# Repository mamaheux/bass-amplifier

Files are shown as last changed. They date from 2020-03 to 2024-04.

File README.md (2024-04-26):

# Bass-Amplifier
Bass-Amplifier is a project to create our own bass guitar amplifier. The amplifier features are:
 - Digital sound processing
 - Footswitch
 - Tuner output
 - XLR and jack direct output
 - Effect send and return
 - Contour and presence filters
 - 4-band EQ
 - Compressor effect
 - Overdrive effect
 - Octaver effect
 - Delay effect
 - Reverb effect

## Folder Descriptions
### cases
This folder contains the CAD files to create the cases.
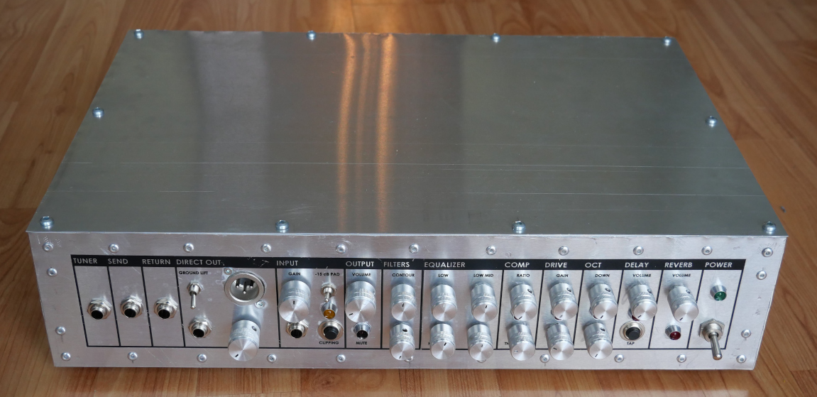
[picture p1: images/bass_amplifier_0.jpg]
Image of bass amplifier

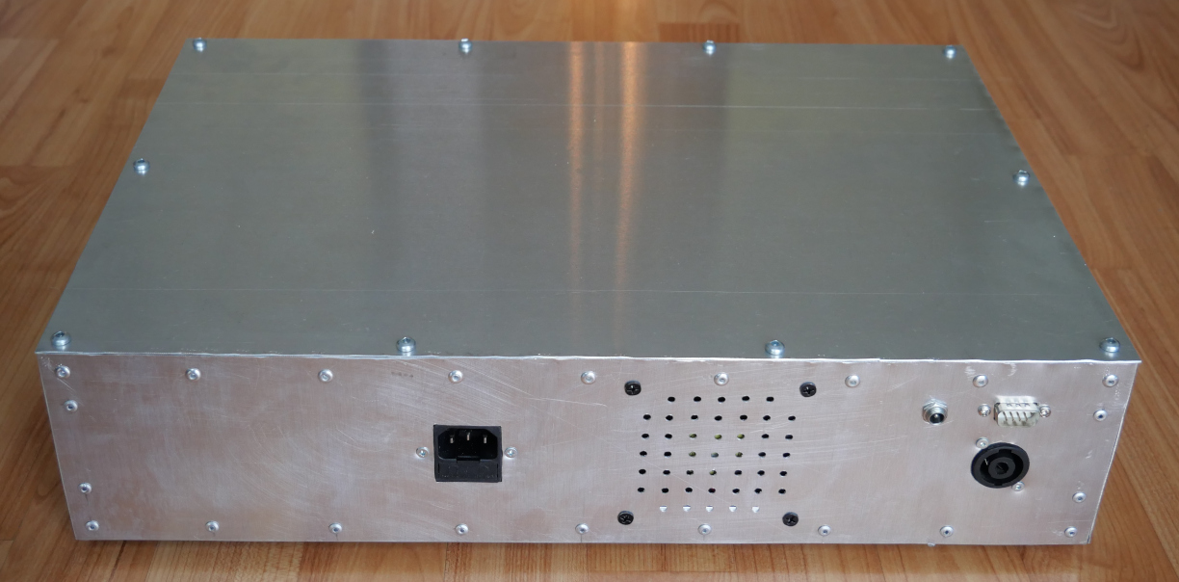
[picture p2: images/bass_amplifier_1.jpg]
Image of bass amplifier

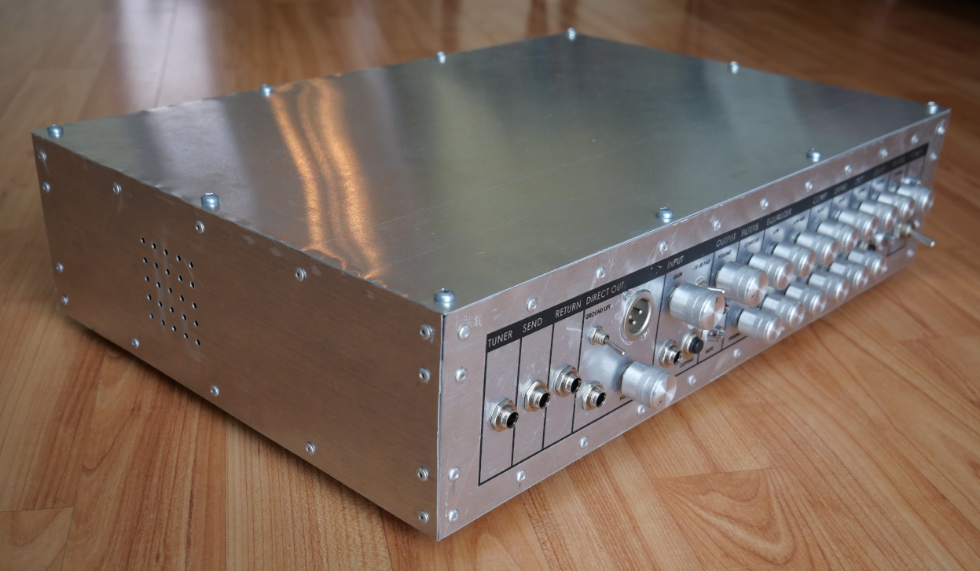
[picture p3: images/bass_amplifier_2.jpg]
Image of bass amplifier

Image of bass amplifier
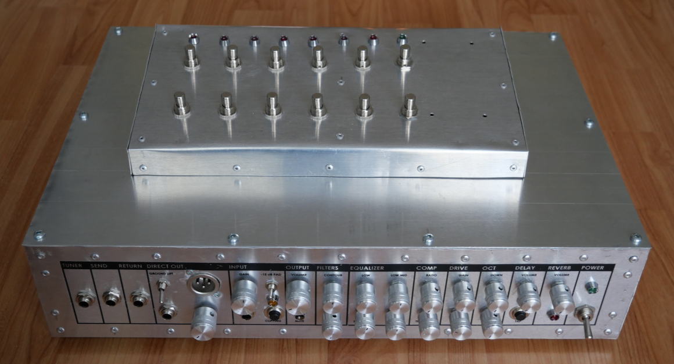
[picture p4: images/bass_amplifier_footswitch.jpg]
Image of bass amplifier


### code
This folder contains the MCU source code for the footswitch, the bass amplifier signal processor and the bass amplifier controller.

### electronics
This folder contains the schematics and PCB layouts of the bass amplifier.

### tools/signal_processing
This folder contains a Python tool to test the audio effects.
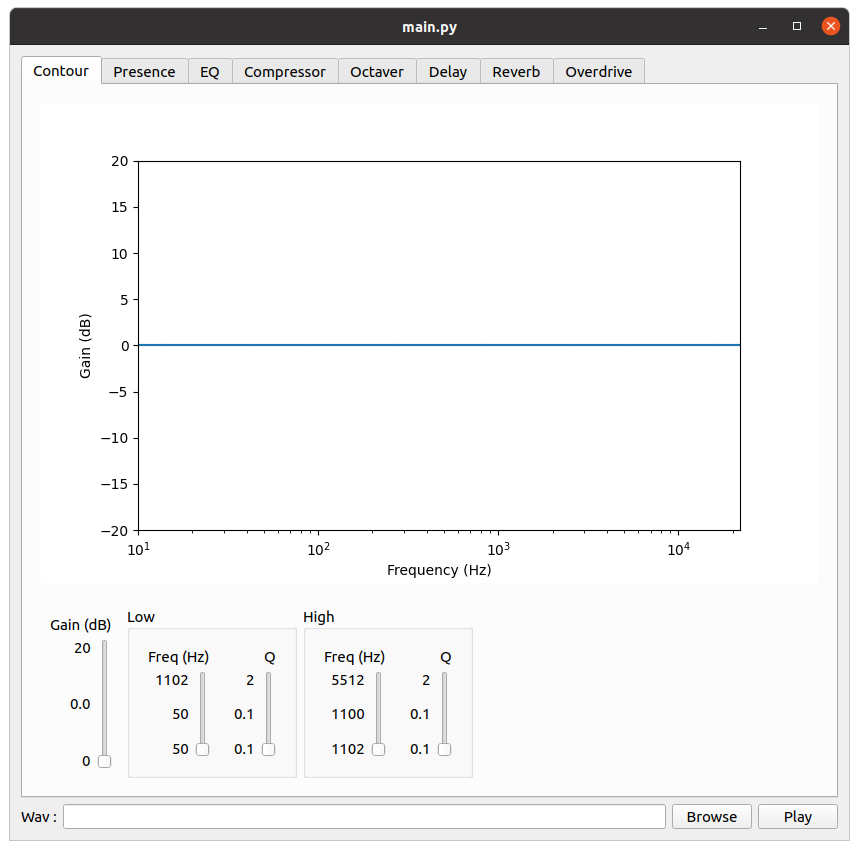
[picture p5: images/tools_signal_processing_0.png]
Image of bass amplifier

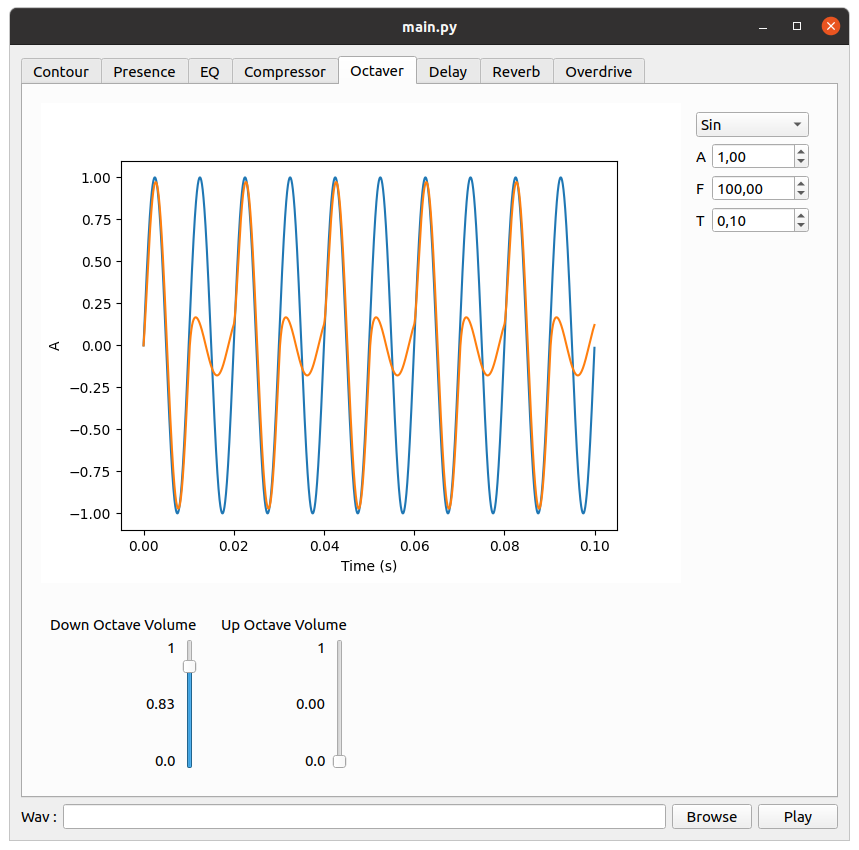
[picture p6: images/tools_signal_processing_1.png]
Image of bass amplifier


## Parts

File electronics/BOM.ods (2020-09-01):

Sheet: control
Item | Qty | Reference(s) | Value | LibPart | Sample | Link
1 | 2 | C1, C2 | 1000µF/25V | Device:CP |  | https://www.futurlec.com/Capacitors/C1000U25Epr.shtml
2 | 2 | C3, C4 | 2.2µF/25V/UL ESR | Device:C |  | https://www.digikey.ca/product-detail/en/taiyo-yuden/TMK212B7225MGHT/587-6358-1-ND/9949944
3 | 2 | C5, C9 | 1µF/10V/UL ESR | Device:C |  | https://www.digikey.ca/product-detail/en/taiyo-yuden/LMK212B7105KGHTR/587-6338-1-ND/9949924
4 | 14 | C6, C7, C10, C11, C12, C13, C14, C16, C17, C18, C19, C20, C21, C22 | 1µF/16V | Device:C |  | https://www.digikey.ca/product-detail/en/kemet/C0805C105Z4VACTU/399-8011-1-ND/3471734
5 | 7 | C8, C15, C23, C24, C25, C26, C27 | 0.1µF/25V | Device:C |  | https://www.digikey.ca/product-detail/en/kemet/C0805C104M3RACTU/399-8000-1-ND/3471723
6 | 2 | D1, D2 | LED_PAD | bass_amplifier:LED_4X
7 | 2 | J1, J3 | Conn_01x06_Male | Connector:Conn_01x06_Male
8 | 1 | J2 | Conn_01x02_Male | Connector:Conn_01x02_Male
9 | 4 | Q1, Q2, Q3, Q4 | TD9944 | bass_amplifier:TD9944 | Yes | https://www.digikey.ca/product-detail/en/microchip-technology/TD9944TG-G/TD9944TG-GCT-ND/7671946
10 | 5 | R1, R2, R3, R4, R5 | 10k | Device:R
11 | 7 | RV1, RV2, RV3, RV4, RV5, RV6, RV7 | 10k | Device:R_POT_Dual_Separate |  | https://futurlec.com/Potentiometers/POT10Kpr.shtml | https://futurlec.com/Switches/KNOB18.shtml
12 | 1 | SW1 | SW_SPST_X3 | bass_amplifier:SW_SPST_X3 |  | https://futurlec.com/Switches/PRBLKpr.shtml
13 | 1 | TH1 | 10k | Device:Thermistor_NTC |  | https://www.futurlec.com/Components_Others/NTC10Kpr.shtml
14 | 1 | U1 | Teensy_LC | bass_amplifier:Teensy_LC |  | https://www.pjrc.com/store/teensylc.html
15 | 1 | U2 | MCP3208 | bass_amplifier:MCP3208 | Yes | https://www.digikey.ca/product-detail/en/microchip-technology/MCP3208-CI-SL/MCP3208-CI-SL-ND/305929
16 | 1 | U3 | 74HC14 | bass_amplifier:74HC14 |  | https://www.digikey.ca/product-detail/en/nexperia-usa-inc/74HC14D-652/1727-3781-ND/763534
17 | 1 | U4 | MAX3232 | bass_amplifier:MAX3232 |  | https://www.digikey.ca/product-detail/en/texas-instruments/MAX3232ECDR/296-19851-1-ND/1120592
18 | 1 | Transformer | Transformer |  |  | https://www.digikey.ca/en/products/detail/triad-magnetics/VPT36-1390/2090072

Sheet: footswitch
Item | Qty | Reference(s) | Value | LibPart | Sample | Link
1 | 17 | C1, C2, C5, C8, C9, C10, C11, C12, C13, C16, C17, C18, C19, C20, C21, C22, C23 | 0.1µF/25V | Device:C |  | https://www.digikey.ca/product-detail/en/kemet/C0805C104M3RACTU/399-8000-1-ND/3471723
2 | 2 | C3, C4 | 1000µF/25V | Device:CP |  | https://www.futurlec.com/Capacitors/C1000U25Epr.shtml
3 | 2 | C6, C7 | 2.2µF/25V/UL low ESR | Device:C |  | https://www.digikey.ca/product-detail/en/taiyo-yuden/TMK212B7225MGHT/587-6358-1-ND/9949944
4 | 2 | C14, C15 | 1µF/10V/UL ESR | Device:C |  | https://www.digikey.ca/product-detail/en/taiyo-yuden/LMK212B7105KGHTR/587-6338-1-ND/9949924
5 | 2 | D1, D2 | LED | bass_amplifier:LED_4X
6 | 1 | J1 | control | Connector:Conn_01x06_Male
7 | 4 | Q1, Q2, Q3, Q4 | TD9944 | bass_amplifier:TD9944 | Yes | https://www.digikey.ca/product-detail/en/microchip-technology/TD9944TG-G/TD9944TG-GCT-ND/7671946
8 | 24 | R1, R2, R3, R4, R5, R6, R7, R8, R9, R10, R11, R12, R13, R14, R15, R16, R17, R18, R19, R20, R21, R22, R23, R24 | 10k | Device:R
9 | 3 | SW1, SW2, SW3 | SPST | bass_amplifier:SW_SPST_X4
10 | 1 | U1 | Teensy_LC | bass_amplifier:Teensy_LC |  | https://www.pjrc.com/store/teensylc.html
11 | 2 | U2, U3 | 74HC14 | bass_amplifier:74HC14 |  | https://www.digikey.ca/product-detail/en/nexperia-usa-inc/74HC14D-652/1727-3781-ND/763534
12 | 1 | U4 | MAX3232 | bass_amplifier:MAX3232 |  | https://www.digikey.ca/product-detail/en/texas-instruments/MAX3232ECDR/296-19851-1-ND/1120592

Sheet: psu
Item | Qty | Reference(s) | Value | LibPart | Sample | Link
1 | 2 | C1, C2 | 10000µF/35V | Device:CP |  | https://www.digikey.ca/product-detail/en/tdk-electronics-inc/B41231A7109M000/495-6149-ND/3493505
2 | 7 | C3, C4, C5, C6, C10, C16, C25, C28 | 1µF/35V | Device:C |  | https://www.digikey.ca/product-detail/en/taiyo-yuden/GMK212B7105KG-T/587-1438-1-ND/1004069
3 | 6 | C7, C8, C14, C20, C22, C23 | 2.2µF/25V/UL ESR | Device:C |  | https://www.digikey.ca/product-detail/en/taiyo-yuden/TMK212B7225MGHT/587-6358-1-ND/9949944
4 | 2 | C9, C15 | 33µF/35V/260mOhm | Device:CP |  | https://www.digikey.ca/product-detail/en/panasonic-electronic-components/EEE-FP1V330AP/PCE4551CT-ND/1701050
5 | 2 | C11, C17 | 0.33µF | Device:C |  | https://www.digikey.ca/product-detail/en/w%C3%BCrth-elektronik/885012207101/732-7676-1-ND/5454303
6 | 2 | C12, C18 | 0.1µF | Device:C |  | https://www.digikey.ca/product-detail/en/kemet/C0805C104M3RACTU/399-8000-1-ND/3471723
7 | 1 | C13 | 330µF/16V/160mOhm | Device:CP |  | https://www.digikey.ca/en/products/detail/united-chemi-con/EMZR160ADA331MF80G/5824761
8 | 1 | C19 | 330µF/6.3V/160mOhm | Device:CP |  | https://www.digikey.ca/product-detail/en/panasonic-electronic-components/EEE-FPJ331XAP/PCE4517CT-ND/1701016
9 | 2 | C21, C24, C27 | 470µF/16V | Device:CP |  | https://www.futurlec.com/Capacitors/C470U16Epr.shtml
10 | 1 | C26 | 47µF/6.3V | Device:C |  | https://www.digikey.ca/product-detail/en/murata-electronics/GRM219R60J476ME44D/490-13249-1-ND/5877457
11 | 1 | D1 | BR81 | Diode_Bridge:ABS2 |  | https://www.futurlec.com/Diodes/BR81pr.shtml
12 | 2 | D2, D3 | SS34/40V/4A | Device:D_Schottky |  | https://www.digikey.ca/product-detail/en/on-semiconductor/SS34/SS34FSCT-ND/2094459
13 | 1 | D4 | LED | Device:LED
14 | 2 | F1, F2 | 1.5A | Device:Fuse |  | https://www.futurlec.com/Components_Others/520FUSES1A5pr.shtml
15 | 1 | F3 | 0.5A | Device:Fuse |  | https://www.futurlec.com/Components_Others/520FUSES0A5pr.shtml
16 | 1 | J1 | Conn_01x03_Female | Connector:Conn_01x03_Female
17 | 1 | J2 | control board | Connector:Conn_01x06_Male
18 | 1 | J3 | processing | Connector:Conn_01x08_Male
19 | 1 | J4 | processing | Connector:Conn_01x06_Male
20 | 1 | J5 | pedals | Connector:Conn_01x02_Male
21 | 1 | J6 | FAN | Connector:Conn_01x02_Male
22 | 2 | L1, L2 | 68µH/Sumida CDRH104R-680MC | Device:L |  | https://www.digikey.ca/product-detail/en/sumida-america-components-inc/CDRH104RNP-680NC/308-2170-1-ND/3946461
23 | 1 | Q1 | PHB21N06LT | Device:Q_NMOS_DGS |  | https://www.digikey.ca/en/products/detail/nexperia-usa-inc/PHB21N06LT-118/1157487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
24 | 5 | R1, R2, R5, R8, R9 | 0 | Device:R
25 | 2 | R3, R6 | 3.01k | Device:R
26 | 1 | R4 | 348 | Device:R
27 | 1 | R7 | 976 | Device:R
28 | 1 | R10 | 16.5k | Device:R
29 | 1 | R11 | 10k | Device:R
30 | 2 | R13, R14 | inf | Device:R
31 | 1 | R15 | 309 | Device:R
32 | 1 | U1 | MC7815 | bass_amplifier:MC7815 |  | https://www.digikey.ca/en/products/detail/on-semiconductor/MC7815CD2TR4G/919342
33 | 1 | U2 | MC7915 | bass_amplifier:MC7915 |  | https://www.digikey.ca/product-detail/en/on-semiconductor/MC7915CD2TR4G/MC7915CD2TR4GOSCT-ND/3462351
34 | 2 | U3, U4 | MIC4684 | bass_amplifier:MIC4684 | Yes | https://www.digikey.ca/product-detail/en/microchip-technology/MIC4684YM-TR/576-1553-1-ND/1121890
35 | 1 | U5 | MC7809 | bass_amplifier:MC7809 |  | https://www.digikey.ca/product-detail/en/on-semiconductor/MC7809CD2TR4G/MC7809CD2TR4GOSCT-ND/3487393
36 | 1 | U6 | MIC37152 | bass_amplifier:MIC37152 | Yes | https://www.digikey.ca/product-detail/en/microchip-technology/MIC37152YM-TR/MIC37152YM-CT-ND/9923709
37 | 1 | U7 | NIS5112 | bass_amplifier:NIS5112 |  | https://www.digikey.ca/product-detail/en/on-semiconductor/NIS5112D2R2G/NIS5112D2R2GOSCT-ND/3487452

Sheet: processing
Item | Qty | Reference(s) | Value | LibPart | Sample | Link
1 | 4 | C1, C2, C3, C4 | 1000µF/25V | Device:CP |  | https://www.futurlec.com/Capacitors/C1000U25Epr.shtml
2 | 22 | C5, C6, C7, C8, C9, C10, C11, C12, C13, C14, C15, C16, C17, C18, C30, C34, C35, C37, C55, C56, C57, C58 | 2.2µF/25V/UL ESR | Device:C |  | https://www.digikey.ca/product-detail/en/taiyo-yuden/TMK212B7225MGHT/587-6358-1-ND/9949944
3 | 1 | C19 | 100pF/100V | Device:C |  | https://www.digikey.ca/product-detail/en/samsung-electro-mechanics/CL21C101JCANNNC/1276-1261-1-ND/3889347
4 | 2 | C20, C24 | 220pF/100V | Device:C |  | https://www.digikey.ca/product-detail/en/samsung-electro-mechanics/CL21B221KCANNNC/1276-2476-1-ND/3890562
5 | 9 | C21, C26, C28, C29, C33, C36, C41, C42, C46 | 10µF/50V | Device:C |  | https://www.digikey.ca/product-detail/en/samsung-electro-mechanics/CL31A106MBHNNNE/1276-6736-1-ND/5961595
6 | 1 | C22 | 0.1µF/100V | Device:C |  | https://www.digikey.ca/product-detail/en/samsung-electro-mechanics/CL21B104KCFSFNE/1276-2923-1-ND/3891009
7 | 1 | C23 | 0.22µF/100V | Device:C |  | https://www.digikey.ca/product-detail/en/samsung-electro-mechanics/CL21B224KCFSFNE/1276-2949-1-ND/3891035
8 | 1 | C25 | 1nF/100V | Device:C |  | https://www.digikey.ca/product-detail/en/samsung-electro-mechanics/CL21B102KCANNNC/1276-1169-1-ND/3889255
9 | 3 | C27, C31, C32 | 4.7nF/100V | Device:C |  | https://www.digikey.ca/product-detail/en/samsung-electro-mechanics/CL21B472KCANNNC/1276-2524-1-ND/3890610
10 | 1 | C38 | 0.047µF/100V | Device:C |  | https://www.digikey.ca/product-detail/en/w%C3%BCrth-elektronik/885012207126/732-12090-1-ND/9346110
11 | 2 | C39, C40 | 3.3µF/25V | Device:C |  | https://www.digikey.ca/product-detail/en/w%C3%BCrth-elektronik/885012107017/732-7627-1-ND/5454254
12 | 1 | C43 | 3600pF/50V | Device:C |  | https://www.digikey.ca/product-detail/en/murata-electronics/GRM2165C1H362JA01D/490-3318-1-ND/702859
13 | 2 | C44, C45 | 220pF/50V | Device:C |  | https://www.digikey.ca/product-detail/en/kemet/C0805C221M5RACTU/399-8039-1-ND/3471762
14 | 4 | C47, C48, C53, C54 | 0.1µF/25V | Device:C |  | https://www.digikey.ca/product-detail/en/yageo/CC0603KRX7R8BB104/311-1341-1-ND/2103125
15 | 1 | C49 | 47µF/10V | Device:C |  | https://www.digikey.ca/product-detail/en/taiyo-yuden/LMK212BBJ476MG-T/587-5465-1-ND/7067141
16 | 1 | C50 | 10µF/10V | Device:C |  | https://www.digikey.ca/product-detail/en/murata-electronics/GRM21BR71A106KA73L/490-10516-1-ND/5026447
17 | 2 | C51, C52 | 1µF/6.3V | Device:C |  | https://www.digikey.ca/product-detail/en/yageo/CC0805KKX5R5BB105/311-3417-1-ND/7164438
18 | 8 | D1, D2, D3, D4, D5, D6, D7, D8 | 12V | Device:D_Zener_ALT |  | https://www.futurlec.com/Diodes/BZV55-C12pr.shtml
19 | 2 | D9, D10 | 6.2V | Device:D_Zener_ALT |  | https://www.futurlec.com/Diodes/BZV55-C6V2pr.shtml
20 | 1 | J1 | Conn_01x08_Male | Connector:Conn_01x08_Male
21 | 1 | J2 | Conn_01x06_Male | Connector:Conn_01x06_Male
22 | 1 | J3 | power_amp | Connector:Conn_01x02_Male
23 | 1 | J4 | control board | Connector:Conn_01x03_Male
24 | 1 | J5 | AudioJack2_X4 | bass_amplifier:AudioJack2_X4
25 | 1 | J6 | AudioJack2_XLR_SW | bass_amplifier:AudioJack2_XLR_SW
26 | 1 | J7 | Conn_01x03_Male | Connector:Conn_01x03_Male
27 | 2 | Q1, Q2 | TD9944 | bass_amplifier:TD9944 | Yes | https://www.digikey.ca/product-detail/en/microchip-technology/TD9944TG-G/TD9944TG-GCT-ND/7671946
28 | 1 | Q3 | MMUN2111LT1 | Device:Q_PNP_ECB_BRT |  | https://www.digikey.ca/product-detail/en/on-semiconductor/MMUN2111LT1G/MMUN2111LT1GOSCT-ND/1139907
29 | 1 | Q4 | MMBT2222A | Device:Q_NPN_BCE |  | https://www.digikey.ca/product-detail/en/diodes-incorporated/MMBT2222A-7-F/MMBT2222A-FDICT-ND/815723
30 | 8 | R1, R4, R5, R8, R16, R18, R21, R70 | 0 | Device:R
31 | 4 | R2, R6, R11, R19 | inf | Device:R
32 | 16 | R3, R12, R15, R30, R31, R38, R39, R42, R43, R48, R49, R53, R56, R57, R63, R65 | 10k | Device:R
33 | 1 | R7 | 47.5k | Device:R
34 | 1 | R9 | 12.1K | Device:R
35 | 1 | R10 | 1M | Device:R
36 | 1 | R13 | 12.1k | Device:R
37 | 1 | R14 | 221 | Device:R
38 | 1 | R17 | 2.21k | Device:R
39 | 1 | R20 | 56.2k | Device:R
40 | 1 | R22 | 23.7k | Device:R
41 | 8 | R23, R24, R27, R28, R35, R46, R47, R50 | 5.11k | Device:R
42 | 5 | R25, R29, R44, R45, R51 | 20k | Device:R
43 | 2 | R26, R34 | 10.2k | Device:R
44 | 4 | R32, R33, R40, R41 | 1k | Device:R
45 | 2 | R36, R37 | 100k | Device:R
46 | 1 | R52 | 4.75k | Device:R
47 | 7 | R54, R55, R59, R60, R66, R68, R69 | 2k | Device:R
48 | 2 | R58, R61 | 470 | Device:R
49 | 1 | R62 | 3.09k | Device:R
50 | 1 | R64 | 15.4k | Device:R
51 | 1 | R67 | 560 | Device:R
52 | 2 | R71, R72 | inf or 47k | Device:R
53 | 1 | RV1 | 10k | Device:R_POT_Dual_Separate
54 | 1 | RV_SW1 | 10k | bass_amplifier:R_POT_SW
55 | 4 | U1, U2, U4, U5 | TL074 | bass_amplifier:TL074 |  | https://www.digikey.ca/product-detail/en/texas-instruments/TL074CDR/296-1283-1-ND/404931
56 | 2 | U3, U10 | TL072 | bass_amplifier:TL072 |  | https://www.digikey.ca/product-detail/en/stmicroelectronics/TL072CDT/497-2200-1-ND/599107
57 | 1 | U6 | Teensy_4.0 | bass_amplifier:Teensy_4.0
58 | 1 | U7 | MCP6541 | bass_amplifier:MCP6541 |  | https://www.digikey.ca/product-detail/en/microchip-technology/MCP6541T-I-SN/MCP6541T-I-SNCT-ND/8538051
59 | 1 | U8 | SN74LVC2G74 | bass_amplifier:SN74AUC1G74 |  | https://www.digikey.ca/en/products/detail/texas-instruments/SN74LVC2G74DCTR/484721
60 | 1 | U9 | CS4270 | bass_amplifier:CS4270 |  | https://www.digikey.ca/product-detail/en/cirrus-logic-inc/CS4270-CZZ/598-1040-5-ND/923160

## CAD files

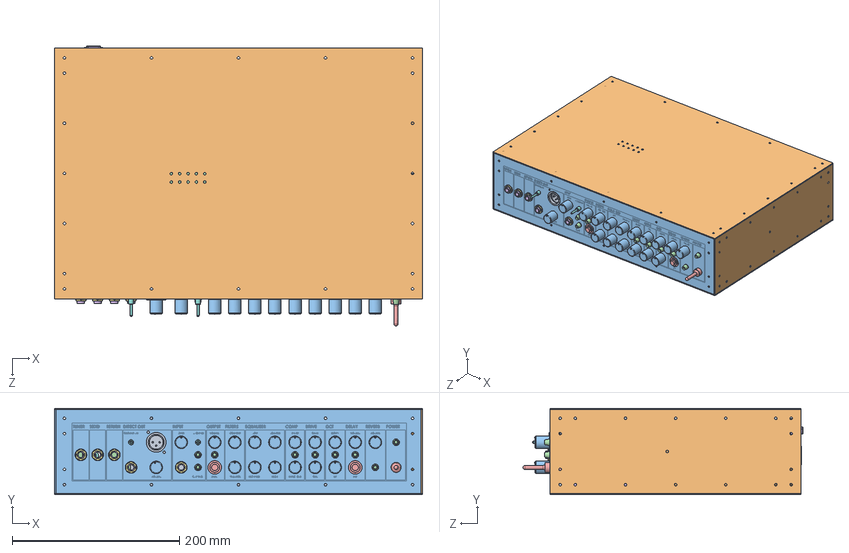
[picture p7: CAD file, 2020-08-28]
cases/amplifier/case.SLDASM
440.0 x 103.2 x 334.7 mm
bottom
transformer_600VA_50V
transformer_50VA_18V
pcb_psu
diode_bridge
power_cap
pcb_amp
pcb_processing
pcb_controller
side_right
side_left
side_back
iec_c14
fan_80mm.step
standoff_m3_10mm x 12
speakon
middle
top
side_front
led_green
toggle_sw_hd
jack x 5
jack_nut x 5
toggle_sw x 2
xlr
pot x 17
knob x 17
led_red x 8
button x 2
dsub-9

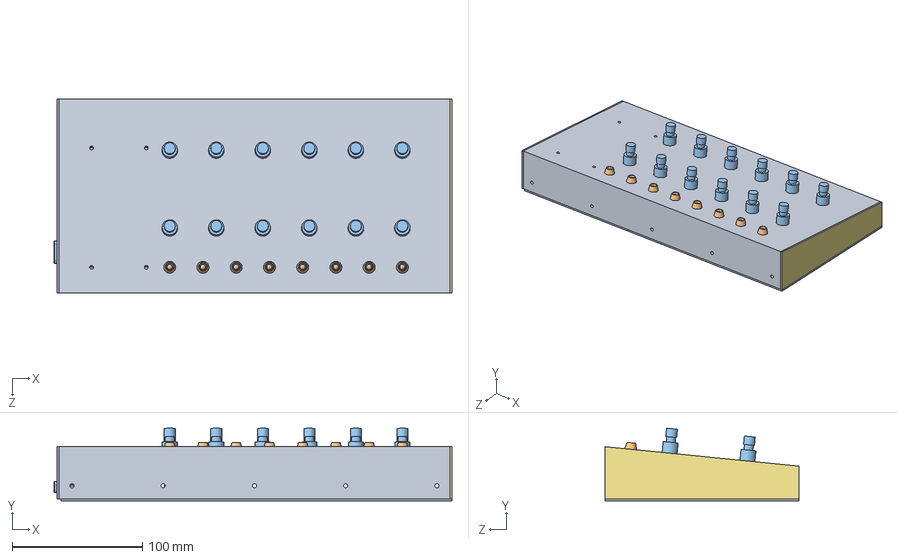
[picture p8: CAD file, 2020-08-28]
cases/footswitch/case.SLDASM
305.4 x 55.8 x 149.2 mm
top
led_red x 8
sw x 12
standoff_m3_10mm x 4
pcb
side_right
side_left
dsub-9
bottom

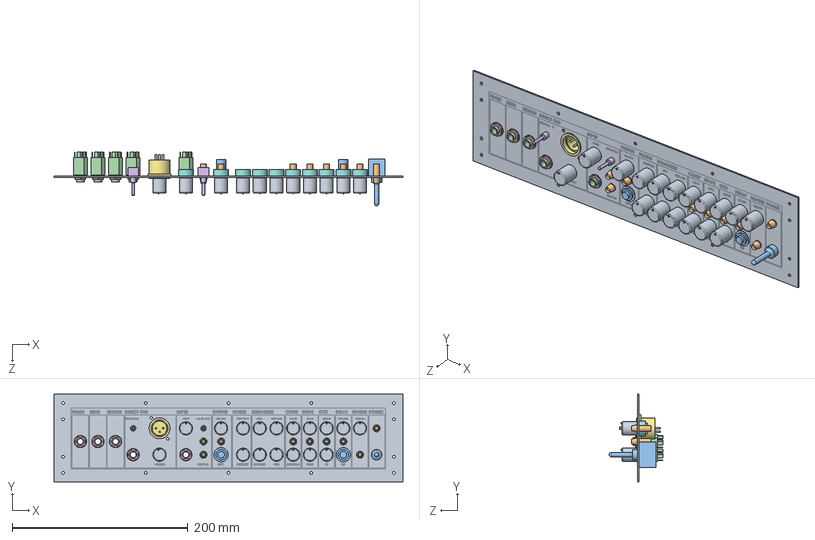
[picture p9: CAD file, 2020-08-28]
cases/amplifier/front.SLDASM
396.8 x 100.0 x 61.0 mm
side_front
led_green
toggle_sw_hd
jack x 5
jack_nut x 5
toggle_sw x 2
xlr
pot x 17
knob x 17
led_red x 8
button x 2

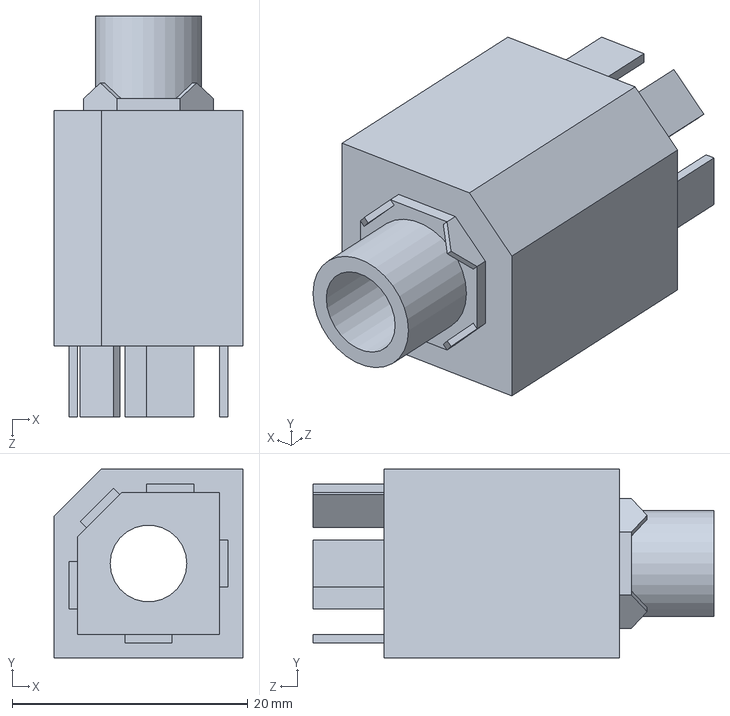
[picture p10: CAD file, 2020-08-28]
cases/amplifier/pieces/jack.SLDPRT
16.0 x 16.0 x 34.0 mm

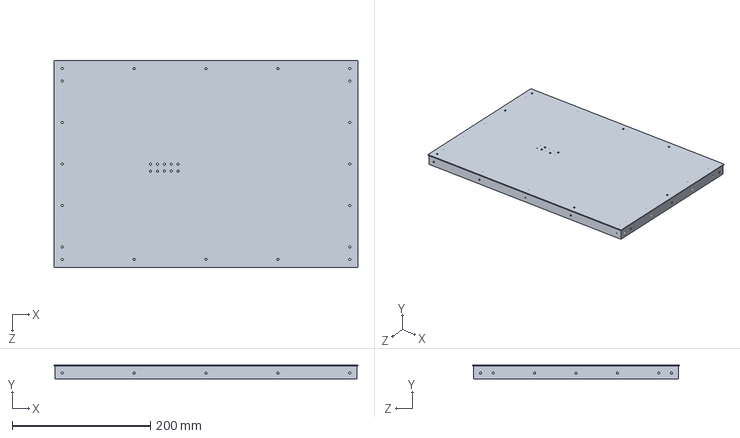
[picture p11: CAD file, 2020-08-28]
cases/amplifier/plates/top.SLDPRT
440.0 x 20.6 x 300.0 mm

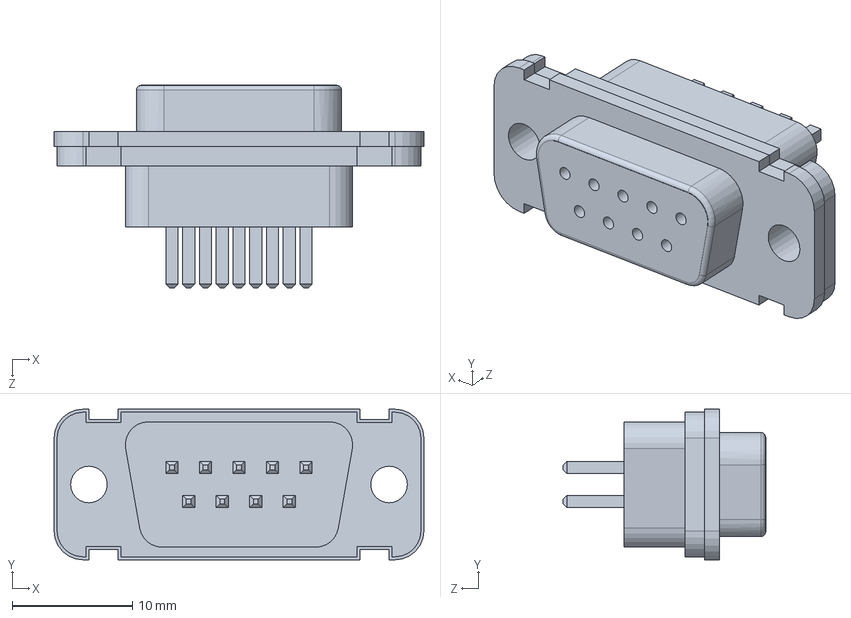
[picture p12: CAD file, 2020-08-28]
cases/footswitch/pieces/dsub-9.SLDPRT
30.8 x 12.5 x 16.9 mm

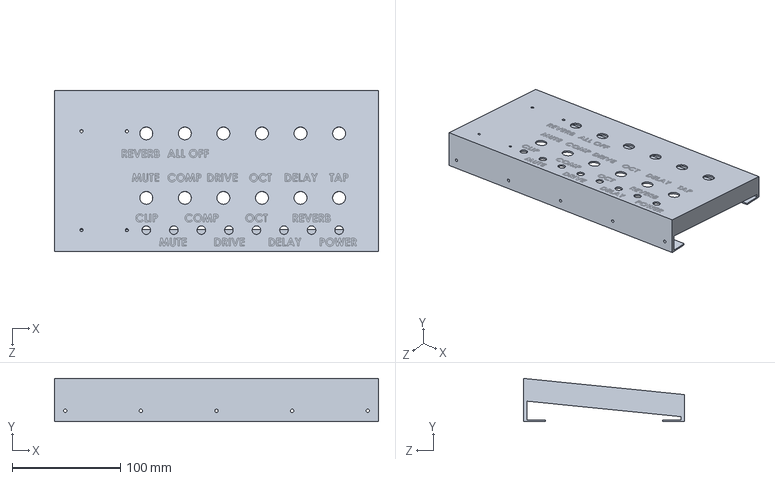
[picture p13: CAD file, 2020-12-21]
cases/footswitch/plates/top.SLDPRT
300.0 x 40.0 x 149.2 mm

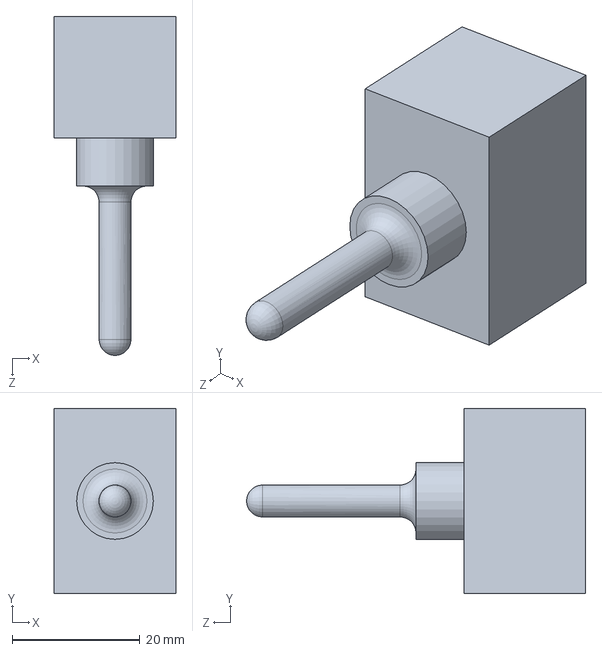
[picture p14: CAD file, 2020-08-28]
cases/amplifier/pieces/toggle_sw_hd.SLDPRT
19.0 x 29.0 x 53.0 mm

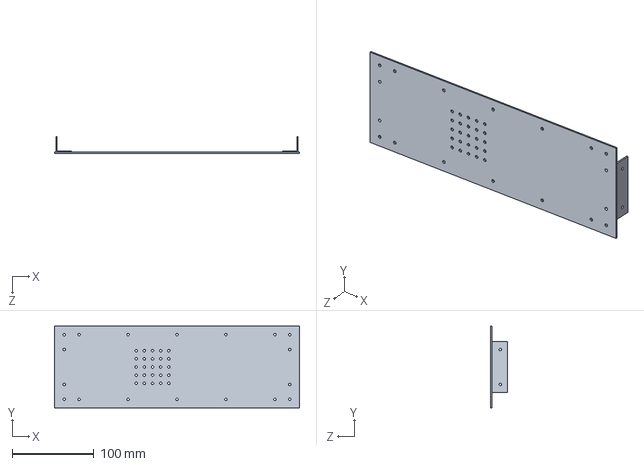
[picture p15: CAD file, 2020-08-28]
cases/amplifier/plates/side_left.SLDPRT
300.0 x 100.0 x 20.6 mm

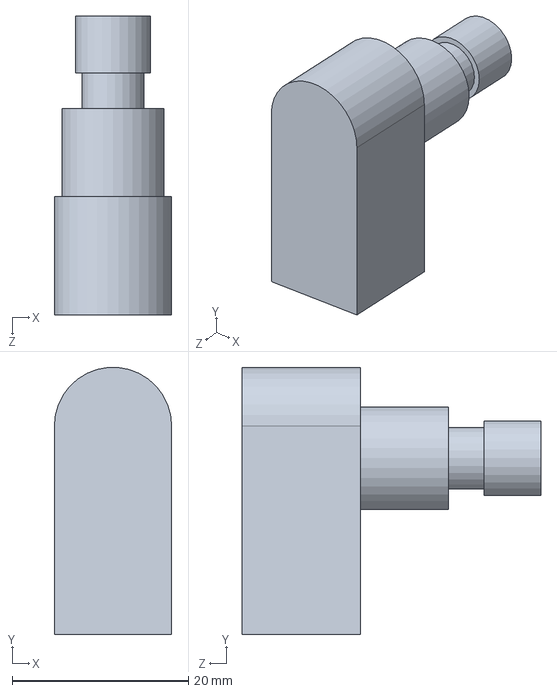
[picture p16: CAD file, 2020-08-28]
cases/footswitch/pieces/sw.SLDPRT
13.3 x 30.3 x 33.8 mm

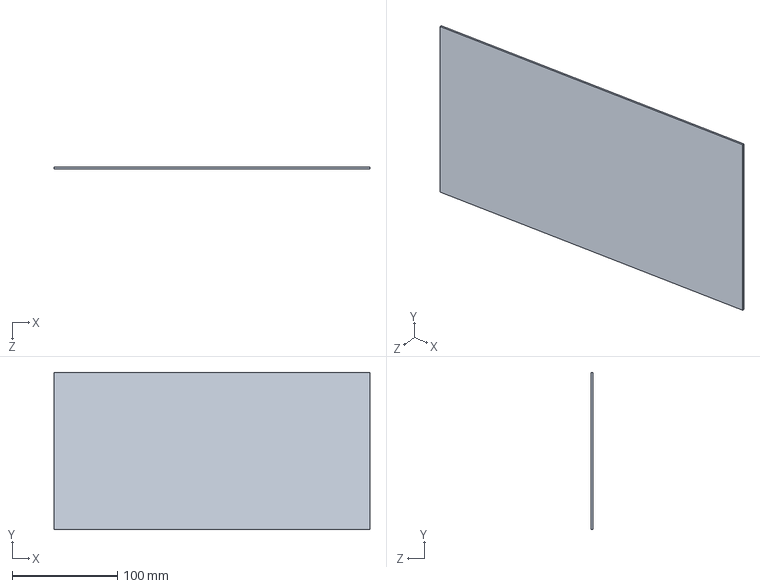
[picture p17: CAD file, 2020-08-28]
cases/footswitch/plates/bottom.SLDPRT
300.0 x 149.2 x 1.59 mm

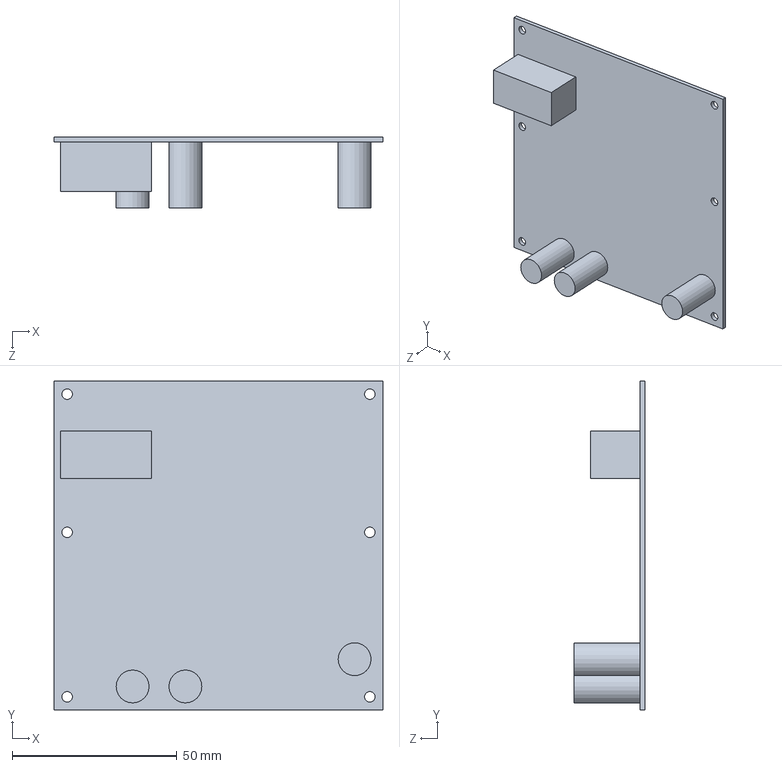
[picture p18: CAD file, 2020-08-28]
cases/amplifier/pieces/pcb_processing.SLDPRT
100.0 x 100.0 x 21.6 mm

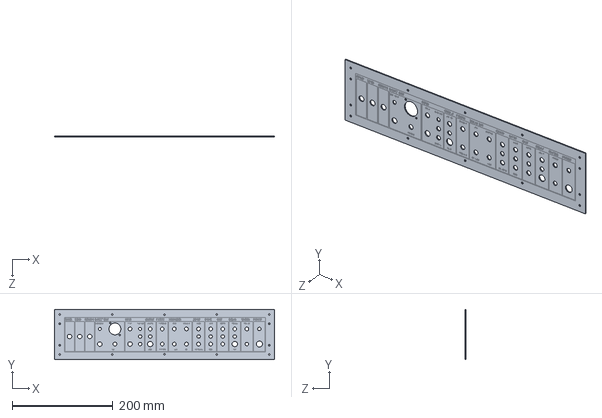
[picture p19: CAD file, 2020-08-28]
cases/amplifier/plates/side_front.SLDPRT
436.8 x 100.0 x 1.59 mm

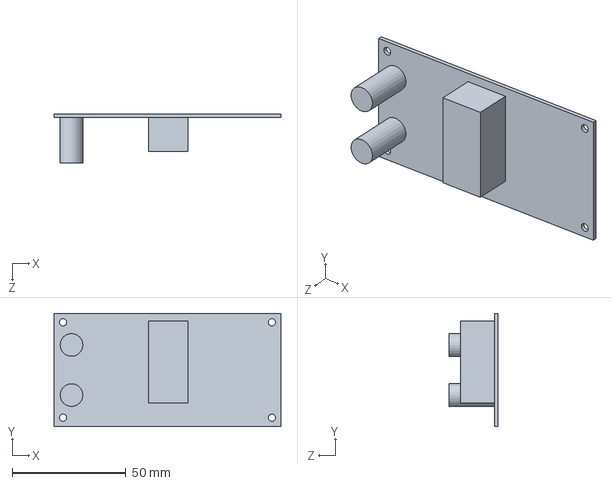
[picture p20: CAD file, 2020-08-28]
cases/footswitch/pieces/pcb.SLDPRT
100.0 x 50.0 x 21.6 mm

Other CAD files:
cases/footswitch/plates/side_right.SLDPRT
cases/amplifier/pieces/led_green.SLDPRT
cases/amplifier/plates/middle.SLDPRT
cases/footswitch/pieces/led_red.SLDPRT
cases/amplifier/pieces/button.SLDPRT
cases/amplifier/pieces/diode_bridge.SLDPRT
cases/amplifier/pieces/fan_80mm.step.SLDPRT
cases/amplifier/pieces/iec_c14.SLDPRT
cases/amplifier/pieces/jack_nut.SLDPRT
cases/amplifier/pieces/knob.SLDPRT
cases/amplifier/pieces/led_red.SLDPRT
cases/amplifier/pieces/pcb_amp.SLDPRT
cases/amplifier/pieces/pcb_psu.SLDPRT
cases/amplifier/pieces/pot.SLDPRT
cases/amplifier/pieces/power_cap.SLDPRT
cases/amplifier/pieces/speakon.SLDPRT
cases/amplifier/pieces/standoff_m3_10mm.SLDPRT
cases/amplifier/pieces/toggle_sw.SLDPRT
cases/amplifier/pieces/transformer_50VA_18V.SLDPRT
cases/amplifier/pieces/transformer_600VA_50V.SLDPRT
cases/amplifier/pieces/xlr.SLDPRT
cases/amplifier/plates/bottom.SLDPRT
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

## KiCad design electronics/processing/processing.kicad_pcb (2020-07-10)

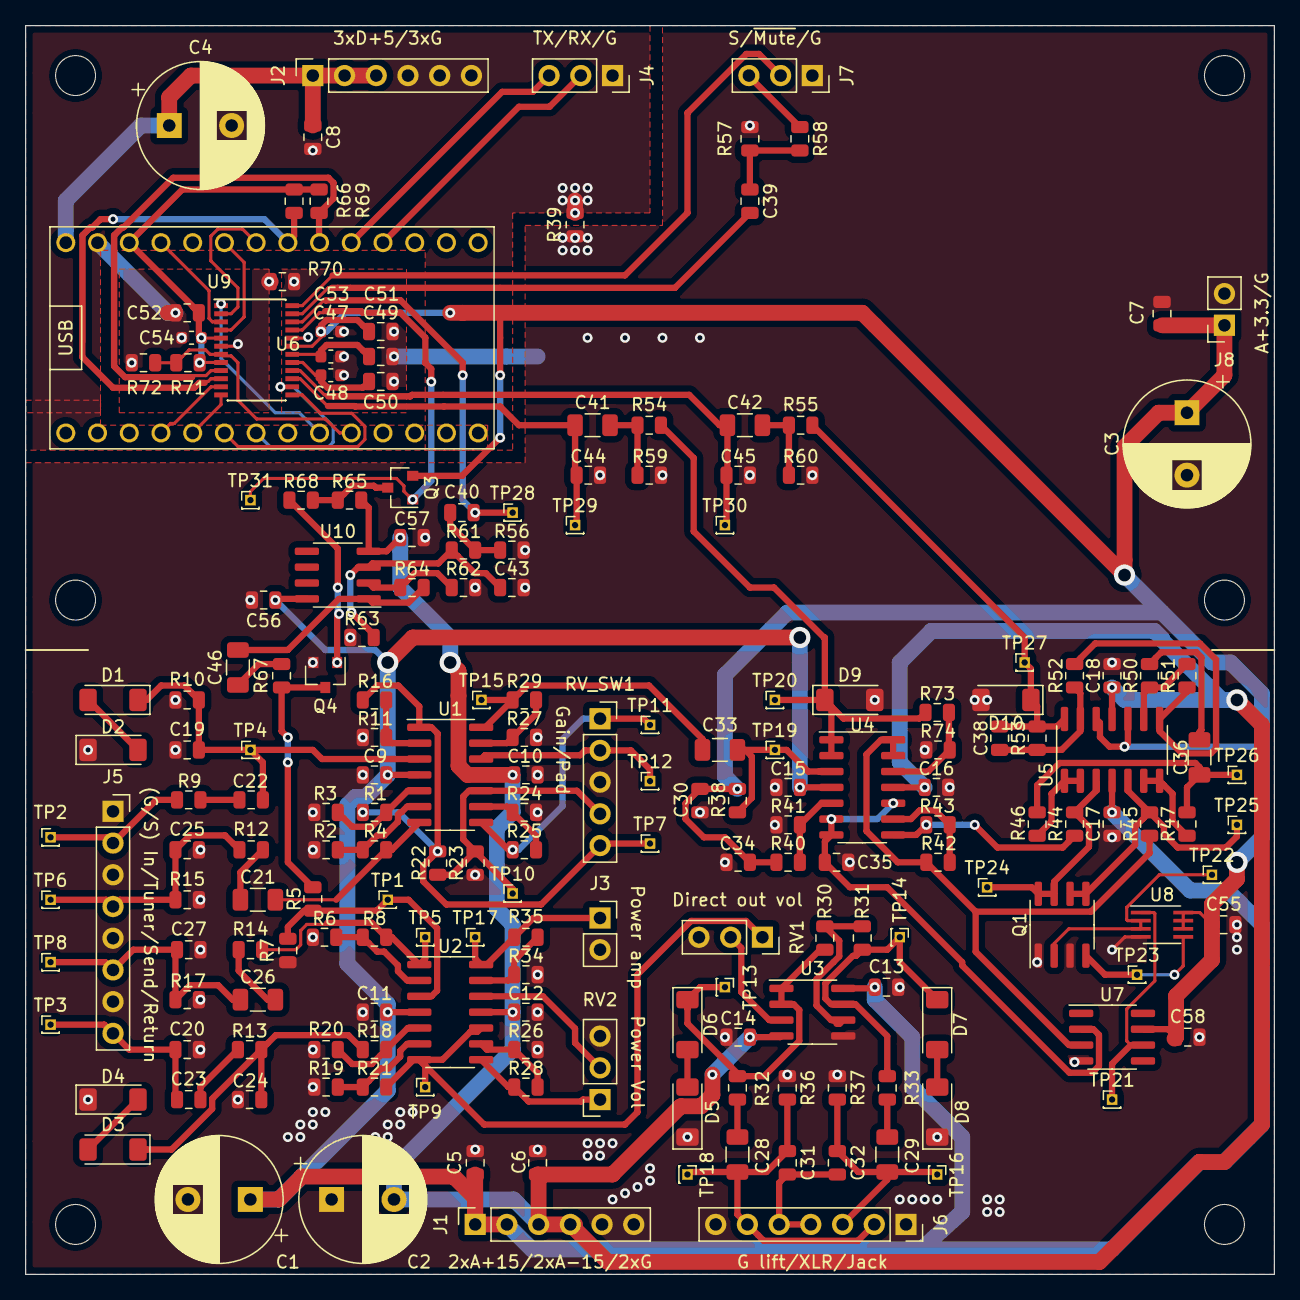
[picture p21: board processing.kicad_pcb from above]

Board: 2 copper layers, 100.0 x 100.0 mm, 194 parts (0 on the bottom side), 106 nets.

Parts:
C1, C2, C3, C4: 1000µF/25V; CP_Radial_D10.0mm_P5.00mm
C5, C6, C7, C8, C9, C10, C11, C12, C13, C14, C15, C16, C17, C18, C30, C34, C35, C55, C56, C57, C58: 2.2µF/25V/UL ESR; C_0805_2012Metric
C19: 100pF/100V; C_0805_2012Metric
C20, C24: 220pF/100V; C_0805_2012Metric
C21, C26, C28, C29, C33, C36, C41, C42, C46: 10µF/50V; C_1206_3216Metric
C22: 0.1µF/100V; C_0805_2012Metric
C23: 0.22µF/100V; C_0805_2012Metric
C25: 1nF/100V; C_0805_2012Metric
C27, C31, C32: 4.7nF/100V; C_0805_2012Metric
C38: 0.047µF/100V; C_0805_2012Metric
C39, C40: 3.3µF/25V; C_0805_2012Metric
C43: 3600pF/50V; C_0805_2012Metric
C44, C45: 220pF/50V; C_0805_2012Metric
C47, C48, C53, C54: 0.1µF/25V; C_0603_1608Metric
C49: 47µF/10V; C_0805_2012Metric
C50: 10µF/10V; C_0805_2012Metric
C51, C52: 1µF/6.3V; C_0805_2012Metric
D1, D2, D3, D4, D5, D6, D7, D8: 12V; D_1806_4516Metric
D9, D10: 6.2V; D_1806_4516Metric
J1, J2: Conn_01x06_Male; PinSocket_1x06_P2.54mm_Vertical
J3: power_amp; PinSocket_1x02_P2.54mm_Vertical
J4: control board; PinSocket_1x03_P2.54mm_Vertical
J5: AudioJack2_X4; PinSocket_1x08_P2.54mm_Vertical
J6: AudioJack2_XLR_SW; PinSocket_1x07_P2.54mm_Vertical
J7: Conn_01x03_Male; PinSocket_1x03_P2.54mm_Vertical
J8: Conn_01x02_Male; PinSocket_1x02_P2.54mm_Vertical
Q1: TD9944; SOIC-8_3.9x4.9mm_P1.27mm
Q3: MMUN2111LT1; SOT-23
Q4: MMBT2222A; SOT-23
R1, R4, R5, R8, R16, R18, R21, R39, R70: 0; R_0805_2012Metric
R2, R6, R11, R19: inf; R_0805_2012Metric
R3, R12, R15, R30, R31, R38, R40, R41, R42, R43, R53, R56, R57, R63, R65, R73, R74: 10k; R_0805_2012Metric
R7: 47.5k; R_0805_2012Metric
R9: 12.1K; R_0805_2012Metric
R10: 1M; R_0805_2012Metric
R13: 12.1k; R_0805_2012Metric
R14: 221; R_0805_2012Metric
R17: 2.21k; R_0805_2012Metric
R20: 56.2k; R_0805_2012Metric
R22: 23.7k; R_0805_2012Metric
R23, R24, R27, R28, R35, R46, R47, R50: 5.11k; R_0805_2012Metric
R25, R29, R44, R45, R51: 20k; R_0805_2012Metric
R26, R34: 10.2k; R_0805_2012Metric
R32, R33: 1k; R_0805_2012Metric
R36, R37: 100k; R_0805_2012Metric
R52: 4.75k; R_0805_2012Metric
R54, R55, R59, R60, R66, R68, R69: 2k; R_0805_2012Metric
R58, R61: 470; R_0805_2012Metric
R62: 3.09k; R_0805_2012Metric
R64: 15.4k; R_0805_2012Metric
R67: 560; R_0805_2012Metric
R71, R72: inf or 47k; R_0805_2012Metric
RV1, RV2: R_POT; PinSocket_1x03_P2.54mm_Vertical
RV_SW1: 10k; PinSocket_1x05_P2.54mm_Vertical
TP1, TP2, TP3, TP4, TP5, TP6, TP7, TP8, TP9, TP10, TP11, TP12, TP13, TP14, TP15, TP16, TP17, TP18, TP19, TP20, TP21, TP22, TP23, TP24, TP25, TP26, TP27, TP28, TP29, TP30, TP31: TP; PinHeader_1x01_P1.00mm_Vertical
U1, U2, U4, U5: TL074; SOIC-14_3.9x8.7mm_P1.27mm
U3, U10: TL072; SOIC-8_3.9x4.9mm_P1.27mm
U6: Teensy_4.0
U7: MCP6541; SOIC-8_3.9x4.9mm_P1.27mm
U8: SN74AUC1G74; SSOP-8_2.95x2.8mm_P0.65mm
U9: CS4270; TSSOP-24_4.4x7.8mm_P0.65mm

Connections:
/LRCLK: U6.20, U9.2
/MCLK: U6.23, U9.3
/MCU_3.3V: C52.1, C54.1, R66.1, R69.1, R71.2, U6.3V3_1, U9.5, U9.8
/SCL: R66.2, U6.19, U9.10
/SCLK: U6.21, U9.4
/SDA: R69.2, U6.18, U9.9
/SDIN: U6.7, U9.1
/SDOUT: R71.1, R72.2, U6.8, U9.7
/analog/octaver_down/REF+1.65V: C35.1, U4.6, U4.7, U4.10, U7.2
/analog/octaver_down/half_signal_in: R42.2, R45.2, U4.13, U4.14, U7.3
/analog/power_amp_signal: J3.1, R35.1, TP17.1, U2.14
/codec/AD0: U6.2, U9.11
/codec/AD1: U6.3, U9.12
/codec/AD2: U6.4, U9.13
/codec/ADC_input_A: D9.1, R54.2, R73.2, TP20.1, U4.1, U4.2
/codec/ADC_input_B: C38.1, D10.1, R53.1, R55.2, TP27.1, U5.14
/codec/DAC_output: Q4.3, R5.2, R67.1
/codec/INA: C41.1, C44.2, TP29.1, U9.15
/codec/INB: C42.1, C45.2, TP30.1, U9.16
/codec/OUTA: C40.2, TP28.1, U9.22
/codec/OUTB: C39.2, U9.23
/codec/~MUTEA: Q3.1, TP31.1, U9.21
/codec/~MUTEB: J7.2, U9.24
/codec/~RST: U6.5, U9.14
A+3.3V: C3.1, C7.1, C30.1, C34.1, C51.1, C53.1, C55.1, C58.1, J8.1, Q3.2, R38.1, R40.2, U5.10, U5.12, U7.7, U8.6, U8.7, U8.8, U9.19
A+15V: C1.1, C5.1, C9.1, C11.1, C13.1, C15.1, C17.1, C56.1, J1.1, J1.2, U1.4, U2.4, U3.8, U4.4, U5.4, U10.8
A-15V: C2.2, C6.2, C10.1, C12.1, C14.1, C16.1, C18.1, C57.1, J1.3, J1.4, R65.1, U1.11, U2.11, U3.4, U4.11, U5.11, U10.4
D+5V: C4.1, C8.1, J2.1, J2.2, J2.3, U6.VIN
GNDA: C1.2, C2.1, C3.2, C5.2, C6.1, C7.2, C9.2, C10.2, C11.2, C12.2, C13.2, C14.2, C15.2, C16.2, C17.2, C18.2, C19.1, C20.2, C24.2, C25.2, C27.2, C30.2, C34.2, C35.2, C43.1, C44.1, C45.1, C47.2, C48.1, C49.2, C50.1, C51.2, C53.2, C55.2, C56.2, C57.2, C58.2, D2.1, D4.1, D5.1, D8.1, D9.2, D10.2, J1.5, J1.6, J3.2, J5.1, J5.3, J5.5, J5.7, J6.1, J6.7, J7.1, J8.2, Q1.1, Q1.3, Q4.2, R2.2, R3.1, R6.2, R7.1, R10.1, R11.2, R15.2, R17.1, R19.2, R20.1, R23.1, R24.2, R26.2, R27.2, R34.2, R36.1, R37.1, R39.1, R41.1, R56.1, R57.1, R59.1, R60.1, R62.2, R63.1, R70.1, R74.1, RV1.3, RV2.3, RV_SW1.3, U3.5, U7.4, U8.4, U9.20
GNDD: C4.2, C8.2, C52.2, C54.2, J2.4, J2.5, J2.6, J4.1, R39.2, R70.2, R72.1, U6.GND_2, U9.6
unnamed: C19.2, C22.1, D1.1, R10.2, TP4.1, U1.3
unnamed: C20.1, C23.1, J5.8, TP3.1
unnamed: C21.1, R12.2
unnamed: C21.2, R4.1, U1.7
unnamed: C22.2, R9.1
unnamed: C23.2, R13.2
unnamed: C24.1, D3.1, R13.1, R18.2
unnamed: C25.1, J5.4, R12.1, R15.1, TP6.1
unnamed: C26.1, C27.1, J5.6, R17.2, TP8.1
unnamed: C26.2, R14.1
unnamed: C28.1, C31.1, J6.2, J6.6, R36.2, TP18.1
unnamed: C28.2, R32.1
unnamed: C29.1, C32.1, J6.3, R37.2, TP16.1
unnamed: C29.2, R33.1
unnamed: C31.2, C32.2, J6.4, J6.5
unnamed: C33.1, R38.2, TP19.1, U4.3
unnamed: C33.2, R29.1, TP15.1, U1.14
unnamed: C36.1, R50.2
unnamed: C36.2, R46.1, R47.2, TP26.1
unnamed: C38.2, R52.1, R53.2, U5.13
unnamed: C39.1, R57.2, R58.2
unnamed: C40.1, R56.2, R61.2
unnamed: C41.2, R54.1, R59.2
unnamed: C42.2, R55.1, R60.2
unnamed: C43.2, R61.1, R63.2, U10.3
unnamed: C46.1, R67.2
unnamed: C46.2, R64.1, U10.1
unnamed: C47.1, C49.1, U9.18
unnamed: C48.2, C50.2, U9.17
unnamed: D1.2, D2.2
unnamed: D3.2, D4.2
unnamed: D5.2, D6.2
unnamed: D6.1, R30.1, R32.2, TP13.1, U3.1, U3.2
unnamed: D7.1, R31.1, R33.2, TP14.1, U3.7
unnamed: D7.2, D8.2
unnamed: J4.2, U6.16
unnamed: J4.3, U6.17
unnamed: J5.2, R9.2, TP2.1
unnamed: J7.3, R58.1
unnamed: Q1.2, TP22.1, U8.2, U8.3
unnamed: Q1.4, TP23.1, U8.5
unnamed: Q1.5, Q1.6, R45.1, TP25.1, U5.5
unnamed: Q1.7, Q1.8, R44.1, TP24.1, U5.3
unnamed: Q3.3, R65.2, R68.1
unnamed: Q4.1, R68.2
unnamed: R1.1, R3.2, U1.5
unnamed: R1.2, R16.1, R22.2, RV_SW1.5, TP7.1, U1.1
unnamed: R2.1, R4.2, U1.6
unnamed: R5.1, R7.2, TP1.1, U2.3
unnamed: R6.1, R8.2, U2.2
unnamed: R11.1, R16.2, U1.2
unnamed: R8.1, R14.2, TP5.1, U2.1
unnamed: R18.1, R20.2, U2.5
unnamed: R19.1, R21.2, U2.6
unnamed: R21.1, RV1.1, TP9.1, U2.7, U2.10
unnamed: R22.1, R23.2, RV_SW1.4, TP10.1, U1.10
unnamed: R24.1, R25.2, U1.9
unnamed: R25.1, RV_SW1.1, TP11.1, U1.8
unnamed: R26.1, R28.2, U2.9
unnamed: R27.1, R29.2, U1.13
unnamed: R28.1, RV2.1, U2.8
unnamed: R30.2, R31.2, U3.6
unnamed: R34.1, R35.2, U2.13
unnamed: R40.1, R41.2, U4.5
unnamed: R42.1, R43.2, U4.9
unnamed: R43.1, R44.2, U4.8
unnamed: R46.2, U5.1, U5.2
unnamed: R47.1, U5.6, U5.7
unnamed: R50.1, R51.2, U5.9
unnamed: R51.1, R52.2, U5.8
unnamed: R62.1, R64.2, U10.2
unnamed: R73.1, R74.2, U4.12
unnamed: RV1.2, U3.3
unnamed: RV2.2, U2.12
unnamed: RV_SW1.2, TP12.1, U1.12
unnamed: TP21.1, U7.6, U8.1

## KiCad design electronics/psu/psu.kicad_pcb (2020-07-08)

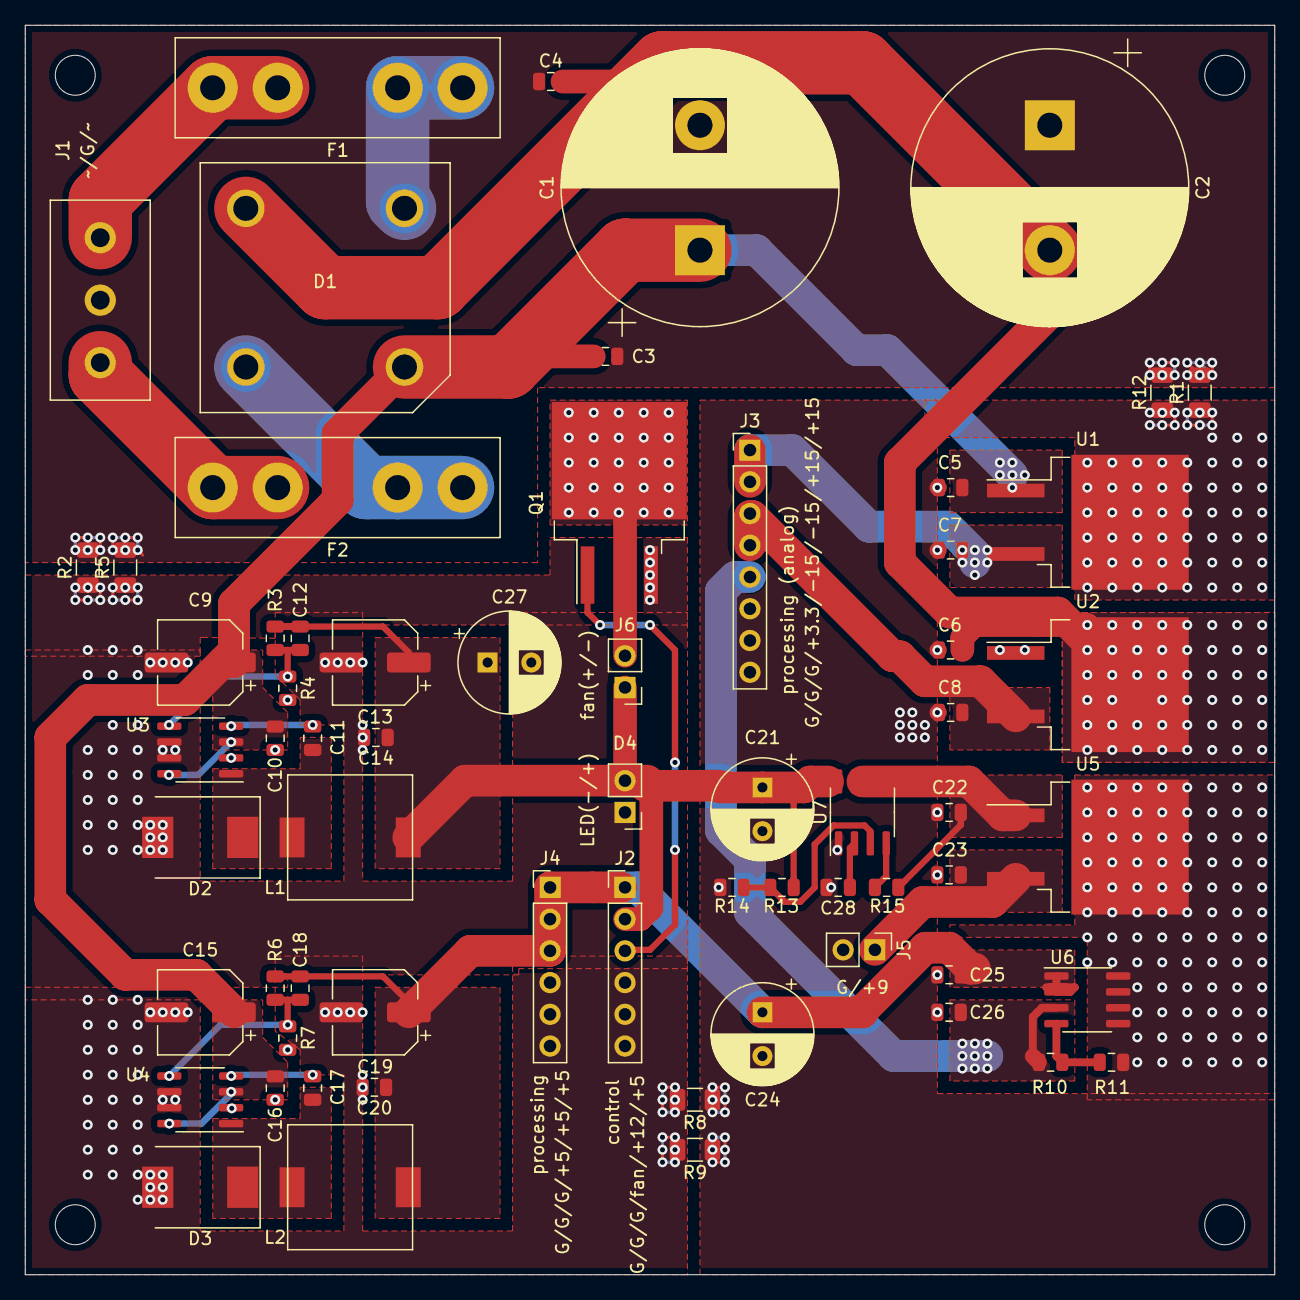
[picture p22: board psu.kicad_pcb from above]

Board: 2 copper layers, 100.0 x 100.0 mm, 65 parts (0 on the bottom side), 28 nets.

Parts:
C1, C2: 10000µF/35V; CP_Radial_D22.0mm_P10.00mm_SnapIn
C3, C4, C5, C6, C10, C16, C25: 1µF/35V; C_0805_2012Metric
C7, C8, C14, C20, C22, C23: 2.2µF/25V/UL ESR; C_0805_2012Metric
C9, C15: 33µF/35V/260mOhm; CP_Elec_6.3x7.7
C11, C17: 0.33µF; C_0805_2012Metric
C12, C18: 0.1µF; C_0805_2012Metric
C13, C19: 330µF/6.3V/160mOhm; CP_Elec_6.3x7.7
C21, C24, C27: 470µF/16V; CP_Radial_D8.0mm_P3.50mm
C26: 47µF/6.3V; C_0805_2012Metric
C28: C; C_0805_2012Metric
D1: BR81
D2, D3: SS34/40V/4A; D_SMC
D4: LED; PinHeader_1x02_P2.54mm_Vertical
F1, F2: 1.5A; M205_FUSE
J1: Conn_01x03_Female; transformer_connector
J2: control board; PinHeader_1x06_P2.54mm_Vertical
J3: processing; PinHeader_1x08_P2.54mm_Vertical
J4: processing; PinHeader_1x06_P2.54mm_Vertical
J5: pedals; PinHeader_1x02_P2.54mm_Vertical
J6: FAN; PinHeader_1x02_P2.54mm_Vertical
L1, L2: 68µH/Sumida CDRH104R-680MC; CDRH104RNP-680NC
Q1: PHB21N06LT; TO-263-2
R1, R2, R5, R8, R9, R12: 0; R_1206_3216Metric
R3, R6: 3.01k; R_0805_2012Metric
R4: 348; R_0805_2012Metric
R7: 976; R_0805_2012Metric
R10: 16.5k; R_0805_2012Metric
R11: 10k; R_0805_2012Metric
R13, R14: inf; R_0805_2012Metric
R15: 309; R_0805_2012Metric
U1: MC7815; TO-263-2
U2: MC7915; TO-263-2
U3, U4: MIC4684; SOIC-8_3.9x4.9mm_P1.27mm
U5: MC7809; TO-263-2
U6: MIC37152; SOIC-8_3.9x4.9mm_P1.27mm
U7: NIS5112; SOIC-8_3.9x4.9mm_P1.27mm

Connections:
/+20V: C1.1, C3.1, C5.1, C9.1, C10.1, C15.1, C16.1, D1.1, U1.1, U3.3, U3.8, U4.3, U4.8
/-20V: C2.2, C4.2, C6.2, D1.2, U2.2
/A+3.3V: C26.1, J3.5, R10.1, U6.3
/A+9V: C23.1, J5.1, U5.3
/A+15V: C7.1, J3.1, J3.2, U1.3
/A-15V: C8.2, J3.3, J3.4, U2.3
/D+5V: C18.1, C19.1, C20.1, C24.1, C25.1, J2.1, J4.1, J4.2, J4.3, L2.2, R6.1, U6.1, U6.2
/D+12V: C12.1, C13.1, C14.1, C21.1, C27.1, D4.2, J2.2, J6.1, L1.2, R3.1, R13.2, U7.8
/fan/fan_pwm: J2.3, Q1.1
GND: C1.2, C2.1, C3.2, C4.1, J1.2, R1.2, R2.2, R5.2, R12.2
GNDA: C5.2, C6.1, C7.2, C8.1, C21.2, C22.2, C23.2, C24.2, C25.2, C26.2, C28.2, J3.6, J3.7, J3.8, J5.2, R1.1, R8.1, R9.1, R11.2, R12.1, R14.2, U1.2, U2.1, U5.2, U6.5, U6.6, U6.7, U6.8, U7.1
GNDD: C9.2, C10.2, C13.2, C14.2, C15.2, C16.2, C19.2, C20.2, C27.2, D2.2, D3.2, D4.1, J2.4, J2.5, J2.6, J4.4, J4.5, J4.6, Q1.3, R2.1, R4.2, R5.1, R7.2, R8.2, R9.2, U3.2, U3.6, U3.7, U4.2, U4.6, U4.7
unnamed: C11.1, U3.4
unnamed: C11.2, D2.1, L1.1, U3.1
unnamed: C12.2, R3.2, R4.1, U3.5
unnamed: C17.1, U4.4
unnamed: C17.2, D3.1, L2.1, U4.1
unnamed: C18.2, R6.2, R7.1, U4.5
unnamed: C22.1, R15.2, U5.1, U7.5, U7.6, U7.7
unnamed: C28.1, U7.2
unnamed: D1.3, F2.1
unnamed: D1.4, F1.1
unnamed: F1.2, J1.3
unnamed: F2.2, J1.1
unnamed: J6.2, Q1.2
unnamed: R10.2, R11.1, U6.4
unnamed: R13.1, R14.1, U7.3
unnamed: R15.1, U7.4

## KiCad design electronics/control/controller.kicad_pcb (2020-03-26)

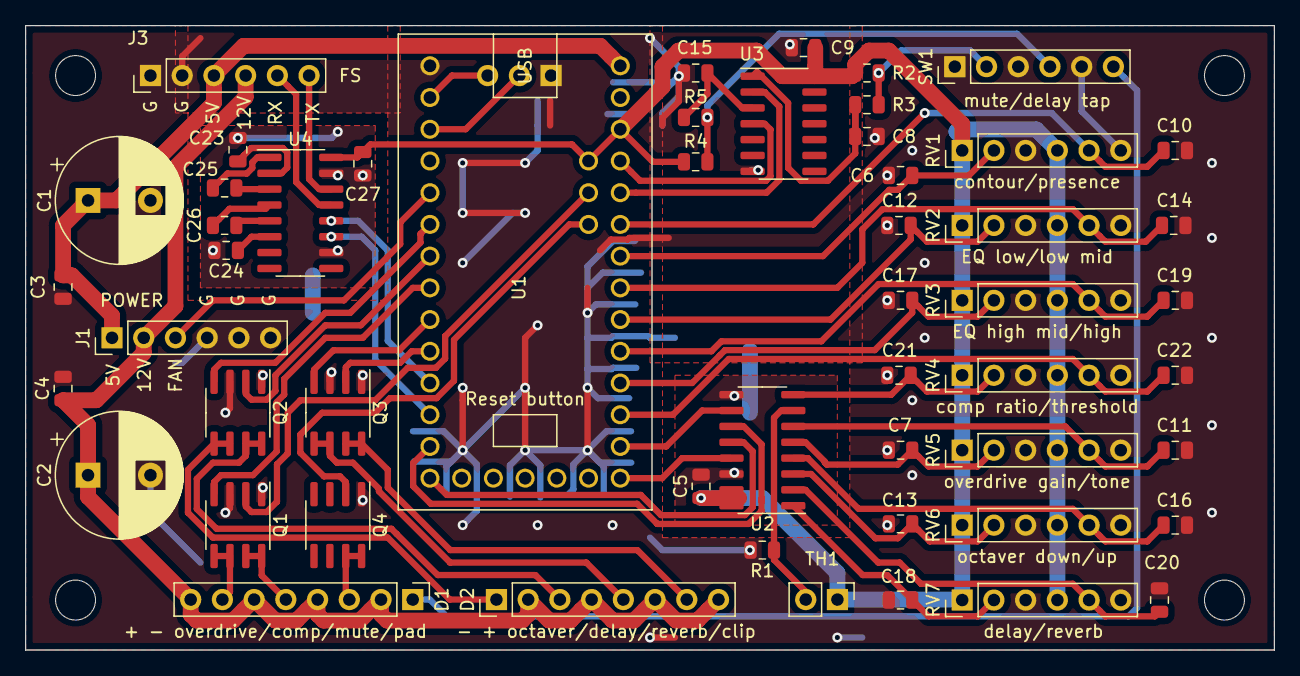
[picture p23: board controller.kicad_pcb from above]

Board: 2 copper layers, 100.0 x 50.0 mm, 54 parts (1 on the bottom side), 57 nets.

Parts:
C1, C2: 1000µF/25V; CP_Radial_D10.0mm_P5.00mm
C3, C4: 2.2µF/25V/UL low ESR; C_0805_2012Metric
C5, C9: 1µF/10V/UL ESR; C_0805_2012Metric
C6, C7, C10, C11, C12, C13, C14, C16, C17, C18, C19, C20, C21, C22: 1µF/16V; C_0805_2012Metric
C8, C15: 0.1µF/25V; C_0805_2012Metric
C23, C24, C25, C26, C27: 0.1µF; C_0805_2012Metric
D1, D2: LED; PinHeader_1x08_P2.54mm_Vertical
J1: Conn_01x06_Male; PinHeader_1x06_P2.54mm_Vertical
J2: Conn_01x03_Male; PinHeader_1x03_P2.54mm_Vertical
J3: footswitch; PinHeader_1x06_P2.54mm_Vertical
Q1, Q2, Q3, Q4: TD9944; SOIC-8_3.9x4.9mm_P1.27mm
R1, R2, R3, R4, R5: 10k; R_0805_2012Metric
RV1, RV2, RV3, RV4, RV5, RV6, RV7: 10k; PinHeader_1x06_P2.54mm_Vertical
SW1: SW_SPST_X3; PinHeader_1x06_P2.54mm_Vertical
TH1: 10k; PinHeader_1x02_P2.54mm_Vertical
U1: Teensy_LC
U2: MCP3208; SOIC-16_3.9x9.9mm_P1.27mm
U3: 74HC14; SOIC-14_3.9x8.7mm_P1.27mm
U4: MAX3232; SOIC-16_3.9x9.9mm_P1.27mm

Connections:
/MCU/3V3: C5.1, C9.1, C27.1, R2.1, R4.1, RV1.1, RV1.4, RV2.1, RV2.4, RV3.1, RV3.4, RV4.1, RV4.4, RV5.1, RV5.4, RV6.1, RV6.4, RV7.1, RV7.4, TH1.1, U1.3V3_1, U1.AREF, U2.15, U2.16, U3.14, U4.16
/MCU/ADC_CS: U1.14, U2.10
/MCU/ADC_MISO: U1.12, U2.12
/MCU/ADC_MOSI: U1.11, U2.11
/MCU/ADC_SCK: U1.13, U2.13
/MCU/DSP_RX: J2.2, U1.1
/MCU/DSP_TX: J2.3, U1.0
/MCU/FS_RS232_RX: J3.5, U4.13
/MCU/FS_RS232_TX: J3.6, U4.14
/MCU/FS_RX: U1.9, U4.12
/MCU/FS_TX: U1.10, U4.11
/MCU/MCU_LED/clipping_LED: Q3.2, U1.8
/MCU/MCU_LED/delay_LED: Q2.2, U1.5
/MCU/MCU_LED/octaver_LED: Q2.4, U1.4
/MCU/MCU_LED/overdrive_LED: Q1.4, U1.6
/MCU/MCU_LED/reverb_LED: Q3.4, U1.7
/MCU/MCU_control_elements/EQ_high_mid_pot: C17.1, RV3.2, U1.16
/MCU/MCU_control_elements/EQ_high_pot: C19.1, RV3.5, U1.17
/MCU/MCU_control_elements/EQ_low_mid_pot: C14.1, RV2.5, U1.19
/MCU/MCU_control_elements/EQ_low_pot: C12.1, RV2.2, U1.18
/MCU/MCU_control_elements/comp_ratio_pot: C21.1, RV4.2, U2.8
/MCU/MCU_control_elements/comp_threshold_pot: C22.1, RV4.5, U1.15
/MCU/MCU_control_elements/contour_pot: C6.1, RV1.2, U1.20
/MCU/MCU_control_elements/delay_tap_button: U1.23, U3.4
/MCU/MCU_control_elements/delay_vol_pot: C18.1, RV7.2, U2.1
/MCU/MCU_control_elements/mute_sw: U1.22, U3.2
/MCU/MCU_control_elements/octaver_down_pot: C13.1, RV6.2, U2.3
/MCU/MCU_control_elements/octaver_up_pot: C16.1, RV6.5, U2.4
/MCU/MCU_control_elements/overdrive_gain_pot: C7.1, RV5.2, U2.5
/MCU/MCU_control_elements/overdrive_tone_pot: C11.1, RV5.5, U2.6
/MCU/MCU_control_elements/presence_pot: C10.1, RV1.5, U1.21
/MCU/MCU_control_elements/reverb_vol_pot: C20.1, RV7.5, U2.2
/MCU/V_temp: R1.1, TH1.2, U2.7
/MCU/comp_LED: Q1.2, U1.24
/MCU/fan_pwm: J1.3, U1.3
/MCU/mute_LED: Q4.2, U1.25
D+5V: C1.1, C3.1, J1.1, J3.3, U1.VIN
D+12V: C2.1, C4.1, D1.2, D1.4, D1.6, D1.8, D2.2, D2.4, D2.6, D2.8, J1.2, J3.4
GNDD: C1.2, C2.2, C3.2, C4.2, C5.2, C6.2, C7.2, C8.2, C9.2, C10.2, C11.2, C12.2, C13.2, C14.2, C15.2, C16.2, C17.2, C18.2, C19.2, C20.2, C21.2, C22.2, C23.2, C24.2, C27.2, J1.4, J1.5, J1.6, J2.1, J3.1, J3.2, Q1.1, Q1.3, Q2.1, Q2.3, Q3.1, Q3.3, Q4.1, R1.2, RV1.3, RV1.6, RV2.3, RV2.6, RV3.3, RV3.6, RV4.3, RV4.6, RV5.3, RV5.6, RV6.3, RV6.6, RV7.3, RV7.6, SW1.1, SW1.3, SW1.5, U1.GND_1, U2.9, U2.14, U3.7, U4.10, U4.15
unnamed: C8.1, R3.1, U3.1
unnamed: C15.1, R5.1, U3.3
unnamed: C23.1, U4.2
unnamed: C24.1, U4.6
unnamed: C25.1, U4.3
unnamed: C25.2, U4.1
unnamed: C26.1, U4.5
unnamed: C26.2, U4.4
unnamed: D1.1, SW1.6
unnamed: D1.3, Q4.7, Q4.8
unnamed: D1.5, Q1.7, Q1.8
unnamed: D1.7, Q1.5, Q1.6
unnamed: D2.1, Q2.5, Q2.6
unnamed: D2.3, Q2.7, Q2.8
unnamed: D2.5, Q3.5, Q3.6
unnamed: D2.7, Q3.7, Q3.8
unnamed: R2.2, R3.2, SW1.2
unnamed: R4.2, R5.2, SW1.4

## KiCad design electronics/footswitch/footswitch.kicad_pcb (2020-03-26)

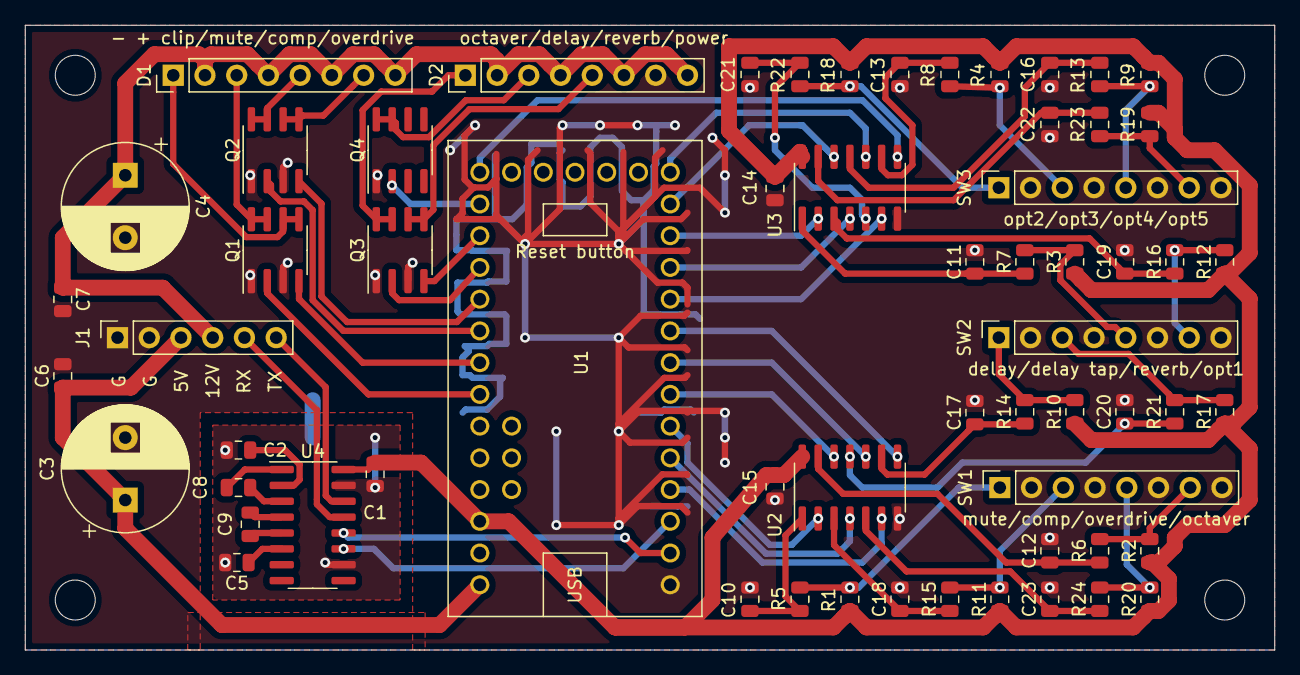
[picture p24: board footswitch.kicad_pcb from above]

Board: 2 copper layers, 100.0 x 50.0 mm, 61 parts (0 on the bottom side), 64 nets.

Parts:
C1, C2, C5, C8, C9, C10, C11, C12, C13, C16, C17, C18, C19, C20, C21, C22, C23: 0.1µF/25V; C_0805_2012Metric
C3, C4: 1000µF/25V; CP_Radial_D10.0mm_P5.00mm
C6, C7: 2.2µF/25V/UL low ESR; C_0805_2012Metric
C14, C15: 1µF/10V/UL ESR; C_0805_2012Metric
D1, D2: LED; PinHeader_1x08_P2.54mm_Vertical
J1: control; PinSocket_1x06_P2.54mm_Vertical
Q1, Q2, Q3, Q4: TD9944; SOIC-8_3.9x4.9mm_P1.27mm
R1, R2, R3, R4, R5, R6, R7, R8, R9, R10, R11, R12, R13, R14, R15, R16, R17, R18, R19, R20, R21, R22, R23, R24: 10k; R_0805_2012Metric
SW1, SW2, SW3: SPST; PinSocket_1x08_P2.54mm_Vertical
U1: Teensy_LC
U2, U3: 74HC14; SOIC-14_3.9x8.7mm_P1.27mm
U4: MAX3232; SOIC-16_3.9x9.9mm_P1.27mm

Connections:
/3V3: C1.2, C14.1, C15.1, R1.1, R2.1, R3.1, R4.1, R9.1, R10.1, R11.1, R12.1, R17.1, R18.1, R19.1, R20.1, U1.3V3_1, U2.14, U3.14, U4.16
/MCU_LED/clipping_LED: Q1.4, U1.19
/MCU_LED/comp_LED: Q2.2, U1.18
/MCU_LED/delay_LED: Q4.2, U1.14
/MCU_LED/mute_LED: Q1.2, U1.20
/MCU_LED/octaver_LED: Q3.2, U1.16
/MCU_LED/overdrive_LED: Q2.4, U1.17
/MCU_LED/reverb_LED: Q3.4, U1.15
/MCU_switchs/comp_sw: U1.3, U2.4
/MCU_switchs/delay_sw: U1.7, U2.8
/MCU_switchs/delay_tap_button: U1.6, U2.10
/MCU_switchs/mute_sw: U1.4, U2.2
/MCU_switchs/octaver_sw: U1.5, U2.12
/MCU_switchs/opt_1_sw: U1.9, U3.4
/MCU_switchs/opt_2_sw: U1.8, U3.6
/MCU_switchs/opt_3_sw: U1.13, U3.8
/MCU_switchs/opt_4_sw: U1.12, U3.10
/MCU_switchs/opt_5_sw: U1.11, U3.12
/MCU_switchs/overdrive_sw: U1.2, U2.6
/MCU_switchs/reverb_sw: U1.10, U3.2
/control_RX: U1.0, U4.12
/control_TX: U1.1, U4.11
D+5V: C3.1, C6.1, J1.3, U1.VIN
D+12V: C4.1, C7.1, D1.2, D1.4, D1.6, D1.8, D2.2, D2.4, D2.6, D2.8, J1.4
GNDD: C1.1, C2.2, C3.2, C4.2, C5.2, C6.2, C7.2, C10.2, C11.2, C12.2, C13.2, C14.2, C15.2, C16.2, C17.2, C18.2, C19.2, C20.2, C21.2, C22.2, C23.2, D2.7, J1.1, J1.2, Q1.1, Q1.3, Q2.1, Q2.3, Q3.1, Q3.3, Q4.1, SW1.2, SW1.4, SW1.6, SW1.8, SW2.2, SW2.4, SW2.6, SW2.8, SW3.2, SW3.4, SW3.6, SW3.8, U1.GND_1, U2.7, U3.7, U4.10, U4.15
unnamed: C2.1, U4.2
unnamed: C5.1, U4.6
unnamed: C8.1, U4.1
unnamed: C8.2, U4.3
unnamed: C9.1, U4.4
unnamed: C9.2, U4.5
unnamed: C10.1, R5.1, U2.1
unnamed: C11.1, R7.1, U3.1
unnamed: C12.1, R6.1, U2.13
unnamed: C13.1, R8.1, U3.9
unnamed: C16.1, R13.1, U3.11
unnamed: C17.1, R14.1, U2.9
unnamed: C18.1, R15.1, U2.3
unnamed: C19.1, R16.1, U3.3
unnamed: C20.1, R21.1, U2.11
unnamed: C21.1, R22.1, U3.5
unnamed: C22.1, R23.1, U3.13
unnamed: C23.1, R24.1, U2.5
unnamed: D1.1, Q1.5, Q1.6
unnamed: D1.3, Q1.7, Q1.8
unnamed: D1.5, Q2.7, Q2.8
unnamed: D1.7, Q2.5, Q2.6
unnamed: D2.1, Q3.7, Q3.8
unnamed: D2.3, Q4.7, Q4.8
unnamed: D2.5, Q3.5, Q3.6
unnamed: J1.5, U4.13
unnamed: J1.6, U4.14
unnamed: R1.2, R5.2, SW1.1
unnamed: R2.2, R6.2, SW1.7
unnamed: R3.2, R7.2, SW2.5
unnamed: R4.2, R8.2, SW3.3
unnamed: R10.2, R14.2, SW2.1
unnamed: R11.2, R15.2, SW1.3
unnamed: R12.2, R16.2, SW2.7
unnamed: R9.2, R13.2, SW3.5
unnamed: R17.2, R21.2, SW2.3
unnamed: R18.2, R22.2, SW3.1
unnamed: R19.2, R23.2, SW3.7
unnamed: R20.2, R24.2, SW1.5

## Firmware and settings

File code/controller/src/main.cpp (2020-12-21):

#include "config.h"
#include "ControlAdc.h"
#include "EffectControls.h"
#include "StatusLed.h"
#include "FanController.h"
#include "DspCommunication.h"

#include <EffectDesign.h>
#include <Communication.h>
#include <Ticker.h>

ControlAdc adc;
EffectControls effectControls(adc);
StatusLed statusLed;
FanController fanController(adc);

ContourDesigner contourDesigner(SAMPLING_FREQUENCY);
PresenceDesigner presenceDesigner(SAMPLING_FREQUENCY);
EqDesigner eqDesigner(SAMPLING_FREQUENCY);
CompressorDesigner compressorDesigner(SAMPLING_FREQUENCY);
OctaverDesigner octaverDesigner(SAMPLING_FREQUENCY);
DelayDesigner delayDesigner(SAMPLING_FREQUENCY, MAX_DELAY);
ReverbDesigner reverbDesigner(SAMPLING_FREQUENCY);
OverdriveDesigner overdriveDesigner(SAMPLING_FREQUENCY);
MuteDesigner muteDesigner(SAMPLING_FREQUENCY);

EffectDesigner* effectDesigners[EFFECT_CODE_COUNT];

ControllerFootswitchCommunication<HardwareSerial2> footswitchCommunication(FOOTSWITCH_SERIAL);
uint32_t lastHeartbeatTimeMs;
bool isHeartbeatPending;

DspCommunication dspCommunication(effectDesigners);

void setupEffectDesigners();
void setupFootswitchCommunication();

void updateEffectDesigners();
void updateStatusLed();
void updateFan();

void updateFootswitchCommunicationFast();
void updateFootswitchCommunicationSlow();
void resetAllEffectEnabledStates();

void dspClippingNotificationHandler();

void footswitchHeatbeatHandler();
void footswitchToogleEffectHandler(uint8_t effectCode);
void footswitchDelayUsHandler(uint32_t delayUs);
void footswitchSetEffectHandler(uint8_t effectCode, bool isEnabled);

Ticker updateEffectDesignersTicker(updateEffectDesigners, EFFECT_DESIGNER_UPDATE_INTERVAL_US, 0, MICROS_MICROS);
Ticker updateStatusLedTicker(updateStatusLed, STATUS_LED_UPDATE_INTERVAL_US, 0, MICROS_MICROS);
Ticker updateFanTicker(updateFan, FAN_UPDATE_INTERVAL_US, 0, MICROS_MICROS);

Ticker updateFootswitchCommunicationFastTicker(updateFootswitchCommunicationFast,
    FOOTSWITCH_COMMUNICATION_FAST_UPDATE_INTERVAL_US, 0, MICROS_MICROS);
Ticker updateFootswitchCommunicationSlowTicker(updateFootswitchCommunicationSlow,
    FOOTSWITCH_COMMUNICATION_SLOW_UPDATE_INTERVAL_US, 0, MICROS_MICROS);

void setup()
{
    delay(STARTUP_DELAY_MS);

    DEBUG_SERIAL.begin(DEBUG_SERIAL_BAUD_RATE);

    adc.begin();
    effectControls.begin();
    statusLed.begin();
    fanController.begin();

    setupEffectDesigners();
    setupFootswitchCommunication();
    dspCommunication.begin(dspClippingNotificationHandler);

    updateEffectDesignersTicker.start();
    updateStatusLedTicker.start();
    updateFanTicker.start();
    updateFootswitchCommunicationFastTicker.start();
    updateFootswitchCommunicationSlowTicker.start();
}

void setupEffectDesigners()
{
    effectDesigners[contourDesigner.effectCode()] = &contourDesigner;
    effectDesigners[presenceDesigner.effectCode()] = &presenceDesigner;
    effectDesigners[eqDesigner.effectCode()] = &eqDesigner;
    effectDesigners[compressorDesigner.effectCode()] = &compressorDesigner;
    effectDesigners[octaverDesigner.effectCode()] = &octaverDesigner;
    effectDesigners[delayDesigner.effectCode()] = &delayDesigner;
    effectDesigners[reverbDesigner.effectCode()] = &reverbDesigner;
    effectDesigners[overdriveDesigner.effectCode()] = &overdriveDesigner;
    effectDesigners[muteDesigner.effectCode()] = &muteDesigner;
}

void setupFootswitchCommunication()
{
    footswitchCommunication.begin(FOOTSWITCH_SERIAL_BAUD_RATE);
    footswitchCommunication.registerHeatbeatHandler(footswitchHeatbeatHandler);
    footswitchCommunication.registerToogleEffectHandler(footswitchToogleEffectHandler);
    footswitchCommunication.registerDelayUsHandler(footswitchDelayUsHandler);
    footswitchCommunication.registerSetEffectHandler(footswitchSetEffectHandler);

    lastHeartbeatTimeMs = millis();
    isHeartbeatPending = true;
}

void loop()
{
    updateEffectDesignersTicker.update();
    updateStatusLedTicker.update();
    updateFanTicker.update();
    updateFootswitchCommunicationFastTicker.update();
    updateFootswitchCommunicationSlowTicker.update();
}

void updateEffectDesigners()
{
    contourDesigner.update(effectControls.getContourGain());
    presenceDesigner.update(effectControls.getPresenceGain());
    eqDesigner.update(effectControls.getEqLowGain(),
        effectControls.getEqLowMidGain(),
        effectControls.getEqHighMidGain(),
        effectControls.getEqHighGain());

    compressorDesigner.update(effectControls.getCompressorThreshold(), effectControls.getCompressorRatio());
    octaverDesigner.update(effectControls.getOctaverDownVolume(), effectControls.getOctaverUpVolume());
    delayDesigner.update(effectControls.getDelayVolume(), effectControls.getDelay());
    reverbDesigner.update(effectControls.getReverbVolume());
    overdriveDesigner.update(effectControls.getOverdriveGain(), effectControls.getOverdriveTone());
    muteDesigner.setIsEnabled(effectControls.getMuteState());

    dspCommunication.update();
}

void updateStatusLed()
{
    statusLed.setCompressorLed(compressorDesigner.isActive());
    statusLed.setOctaverLed(octaverDesigner.isActive());
    statusLed.setDelayLed(delayDesigner.isActive());
    statusLed.setReverbLed(reverbDesigner.isActive());
    statusLed.setOverdriveLed(overdriveDesigner.isActive());
    statusLed.setMuteLed(muteDesigner.isActive());
    statusLed.update();
}

void updateFan()
{
    fanController.update();
}

void updateFootswitchCommunicationFast()
{
    while (footswitchCommunication.receive());
}

void updateFootswitchCommunicationSlow()
{
    footswitchCommunication.sendEffectActiveStates(compressorDesigner.isActive(),
        octaverDesigner.isActive(),
        delayDesigner.isActive(),
        reverbDesigner.isActive(),
        overdriveDesigner.isActive(),
        muteDesigner.isActive());

    if ((millis() - lastHeartbeatTimeMs) > CONTROLLER_FOOTSWITCH_HEARTBEAT_TIMEOUT_MS && isHeartbeatPending)
    {
        resetAllEffectEnabledStates();
        isHeartbeatPending = false;
    }
}

void resetAllEffectEnabledStates()
{
    for (int i = 0; i < EFFECT_CODE_COUNT; i++)
    {
        effectDesigners[i]->setIsEnabled(true);
    }
    muteDesigner.setIsEnabled(false);
}

void dspClippingNotificationHandler()
{
    statusLed.notifyClipping();
    footswitchCommunication.sendClippingNotification();
}

void footswitchHeatbeatHandler()
{
    lastHeartbeatTimeMs = millis();
    isHeartbeatPending = true;
}

void footswitchToogleEffectHandler(uint8_t effectCode)
{
    if (effectCode < EFFECT_CODE_COUNT && effectCode != MUTE_CODE)
    {
        effectDesigners[effectCode]->setIsEnabled(!effectDesigners[effectCode]->isEnabled());
    }
    else if (effectCode == MUTE_CODE)
    {
        effectControls.setMuteState(!effectControls.getMuteState());
    }
}

void footswitchDelayUsHandler(uint32_t delayUs)
{
    effectControls.setDelayUs(delayUs);
}

void footswitchSetEffectHandler(uint8_t effectCode, bool isEnabled)
{
    if (effectCode < EFFECT_CODE_COUNT && effectCode != MUTE_CODE)
    {
        effectDesigners[effectCode]->setIsEnabled(isEnabled);
    }
    else if (effectCode == MUTE_CODE)
    {
        effectControls.setMuteState(isEnabled);
    }
}

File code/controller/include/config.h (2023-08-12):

#ifndef CONFIG_H
#define CONFIG_H

#include <Arduino.h>
#include <SPI.h>

constexpr uint32_t STARTUP_DELAY_MS = 1000;

// Update interval
constexpr uint32_t EFFECT_DESIGNER_UPDATE_INTERVAL_US = 2500;
constexpr uint32_t STATUS_LED_UPDATE_INTERVAL_US = 20000;
constexpr uint32_t FAN_UPDATE_INTERVAL_US = 1000000;
constexpr uint32_t FOOTSWITCH_COMMUNICATION_FAST_UPDATE_INTERVAL_US = 2500;
constexpr uint32_t FOOTSWITCH_COMMUNICATION_SLOW_UPDATE_INTERVAL_US = 50000;

// Effects
constexpr float SAMPLING_FREQUENCY = 48000;
constexpr uint32_t MAX_DELAY = 96000;

// IO
#define DEBUG_SERIAL Serial
constexpr uint32_t DEBUG_SERIAL_BAUD_RATE = 9600;

#define FOOTSWITCH_SERIAL Serial2
constexpr uint32_t FOOTSWITCH_SERIAL_BAUD_RATE = 38400;

#define DSP_SERIAL Serial1
constexpr uint32_t DSP_SERIAL_BAUD_RATE = 38400;

constexpr uint8_t ADC_RESOLUTION = 12;
constexpr uint16_t ADC_MAX_VALUE = 4095;

#define EXTERNAL_ADC_SPI SPI
constexpr uint32_t EXTERNAL_ADC_SPI_CLK = 1600000;
constexpr uint8_t EXTERNAL_ADC_CS_PIN = 14;

enum class AdcSource
{
    INTERNAL_ADC,
    EXTERNAL_ADC
};

struct AdcChannel
{
    AdcSource source;
    uint8_t channel;
};

constexpr uint16_t POT_DEAD_ZONE = 64;

constexpr AdcChannel CONTOUR_GAIN_POT = {AdcSource::INTERNAL_ADC, 20};
constexpr AdcChannel PRESENCE_GAIN_POT = {AdcSource::INTERNAL_ADC, 21};
constexpr AdcChannel EQ_LOW_GAIN_POT = {AdcSource::INTERNAL_ADC, 18};
constexpr AdcChannel EQ_LOW_MID_GAIN_POT = {AdcSource::INTERNAL_ADC, 19};
constexpr AdcChannel EQ_HIGH_MID_GAIN_POT = {AdcSource::INTERNAL_ADC, 16};
constexpr AdcChannel EQ_HIGH_GAIN_POT = {AdcSource::INTERNAL_ADC, 17};
constexpr AdcChannel COMPRESSOR_THRESHOLD_POT = {AdcSource::INTERNAL_ADC, 15};
constexpr AdcChannel COMPRESSOR_RATIO_POT = {AdcSource::EXTERNAL_ADC, 7};
constexpr AdcChannel OCTAVER_DOWM_VOLUME_POT = {AdcSource::EXTERNAL_ADC, 2};
constexpr AdcChannel OCTAVER_UP_VOLUME_POT = {AdcSource::EXTERNAL_ADC, 3};
constexpr AdcChannel DELAY_VOLUME_POT = {AdcSource::EXTERNAL_ADC, 0};
constexpr AdcChannel REVERB_VOLUME_POT = {AdcSource::EXTERNAL_ADC, 1};
constexpr AdcChannel OVERDRIVE_GAIN_POT = {AdcSource::EXTERNAL_ADC, 4};
constexpr AdcChannel OVERDRIVE_TONE_POT = {AdcSource::EXTERNAL_ADC, 5};

constexpr uint8_t DELAY_TAP_PIN = 23;
constexpr uint8_t MUTE_PIN = 22;


constexpr uint8_t COMPRESSOR_LED_PIN = 24;
constexpr uint8_t OCTAVER_LED_PIN = 4;
constexpr uint8_t DELAY_LED_PIN = 5;
constexpr uint8_t REVERB_LED_PIN = 7;
constexpr uint8_t OVERDRIVE_LED_PIN = 6;
constexpr uint8_t MUTE_LED_PIN = 25;
constexpr uint8_t CLIPPING_LED_PIN = 8;


constexpr AdcChannel THERMISTOR = {AdcSource::EXTERNAL_ADC, 6};
constexpr uint8_t FAN_PIN = 3;

// Other
constexpr uint32_t CLIPPING_LED_ON_DURATION_MS = 500;

constexpr float FAN_THERMISTOR_BETA = 3900;
constexpr float FAN_THERMISTOR_RTH1 = 10000;
constexpr float FAN_THERMISTOR_RB = 10000;
constexpr float FAN_THERMISTOR_T_KELVIN = 298.15; //25 °C
constexpr float FAN_THRESHOLD_T_KELVIN = 323.15; // 50 °C

#endif

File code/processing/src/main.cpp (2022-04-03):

#include "config.h"

#include "Cs4270.h"
#include "ControllerCommunication.h"

#include <EffectProcessing.h>
#include <Communication.h>

#ifndef TEST

Cs4270 cs4270;


Compressor<BLOCK_SIZE> compressor;
Presence<BLOCK_SIZE> presence;
Contour<BLOCK_SIZE> contour;
Eq<BLOCK_SIZE> eq;
Overdrive<BLOCK_SIZE> overdrive;
Octaver<BLOCK_SIZE> octaver;
DMAMEM Delay<BLOCK_SIZE, MAX_DELAY> delayEffect;
Reverb<BLOCK_SIZE> reverb;
Mute<BLOCK_SIZE> mute;

Effect<BLOCK_SIZE>* effects[EFFECT_CODE_COUNT];
ControllerCommunication controllerCommunication(effects);


void setupEffects();
float* processAudio(float* input);
bool isOutputClipping(float* output);

void setup()
{
    DEBUG_SERIAL.begin(DEBUG_SERIAL_BAUD_RATE);

    setupEffects();

    cs4270.begin();
    controllerCommunication.begin();
}

void setupEffects()
{
    effects[COMPRESSOR_CODE] = &compressor;
    effects[PRESENCE_CODE] = &presence;
    effects[CONTOUR_CODE] = &contour;
    effects[EQ_CODE] = &eq;
    effects[OVERDRIVE_CODE] = &overdrive;
    effects[OCTAVER_CODE] = &octaver;
    effects[DELAY_CODE] = &delayEffect;
    effects[REVERB_CODE] = &reverb;
    effects[MUTE_CODE] = &mute;
}

void loop()
{
    controllerCommunication.update();

    float input[BLOCK_SIZE];
    float _downOctave[BLOCK_SIZE]; // Too much noise
    if (cs4270.read(_downOctave, input))
    {
        float* output = processAudio(input);

        if (isOutputClipping(output))
        {
            controllerCommunication.notifyClipping();
        }

        while (!cs4270.write(output, output))
        {
            controllerCommunication.update();
        }
    }
}

float* processAudio(float* input)
{
    float* output = compressor.process(input);

    output = presence.process(output);
    output = contour.process(output);
    output = eq.process(output);

    output = overdrive.process(output);
    output = octaver.process(output);

    output = delayEffect.process(output);
    output = reverb.process(output);

    output = mute.process(output);

    return output;
}

bool isOutputClipping(float* output)
{
    for (uint32_t i = 0; i < BLOCK_SIZE; i++)
    {
        if (abs(output[i]) > CLIPPING_VALUE)
        {
            return true;
        }
    }
    return false;
}

#endif

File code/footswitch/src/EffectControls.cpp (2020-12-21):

#include "EffectControls.h"

static volatile bool* isCompressorDirty = nullptr;
static void compressorInterrupt()
{
    if (isCompressorDirty == nullptr)
    {
        return;
    }

    *isCompressorDirty = true;
}

static volatile bool* isOctaverDirty = nullptr;
static void octaverInterrupt()
{
    if (isOctaverDirty == nullptr)
    {
        return;
    }
    
    *isOctaverDirty = true;
}

static volatile bool* isDelayDirty = nullptr;
static void delayInterrupt()
{
    if (isDelayDirty == nullptr)
    {
        return;
    }
    
    *isDelayDirty = true;
}

static volatile bool* isReverbDirty = nullptr;
static void reverbInterrupt()
{
    if (isReverbDirty == nullptr)
    {
        return;
    }
    
    *isReverbDirty = true;
}

static volatile bool* isOverdriveDirty = nullptr;
static void overdriveInterrupt()
{
    if (isOverdriveDirty == nullptr)
    {
        return;
    }
    
    *isOverdriveDirty = true;
}

static volatile bool* isMuteDirty = nullptr;
static void muteInterrupt()
{
    if (isMuteDirty == nullptr)
    {
        return;
    }
    
    *isMuteDirty = true;
}

static volatile uint32_t* delayUs = nullptr;
static volatile bool* isDelayUsDirty = nullptr;
static volatile uint32_t lastDelayTapUs = 0;
static void delayTapInterrupt()
{
    if (delayUs == nullptr || isDelayUsDirty == nullptr)
    {
        return;
    }

    uint32_t timeUs = micros();
    *delayUs = timeUs - lastDelayTapUs;
    lastDelayTapUs = timeUs;
    *isDelayUsDirty = true;
}

static volatile bool* isOpt1Dirty = nullptr;
static void opt1Interrupt()
{
    if (isOpt1Dirty == nullptr)
    {
        return;
    }
    
    *isOpt1Dirty = true;
}

static volatile bool* isOpt2Dirty = nullptr;
static void opt2Interrupt()
{
    if (isOpt2Dirty == nullptr)
    {
        return;
    }
    
    *isOpt2Dirty = true;
}

static volatile bool* isOpt3Dirty = nullptr;
static void opt3Interrupt()
{
    if (isOpt3Dirty == nullptr)
    {
        return;
    }
    
    *isOpt3Dirty = true;
}

static volatile bool* isOpt4Dirty = nullptr;
static void opt4Interrupt()
{
    if (isOpt4Dirty == nullptr)
    {
        return;
    }
    
    *isOpt4Dirty = true;
}

static volatile bool* isOpt5Dirty = nullptr;
static void opt5Interrupt()
{
    if (isOpt5Dirty == nullptr)
    {
        return;
    }
    
    *isOpt5Dirty = true;
}

EffectControls::EffectControls(ControllerFootswitchCommunication<decltype(CONTROLLER_SERIAL)>& controllerCommunication) :
    m_controllerCommunication(controllerCommunication),

    m_isCompressorDirty(false),
    m_isOctaverDirty(false),
    m_isDelayDirty(false),
    m_isReverbDirty(false),
    m_isOverdriveDirty(false),
    m_isMuteDirty(false),

    m_delayUs(0),
    m_isDelayUsDirty(false),

    m_isOpt1Dirty(false),
    m_isOpt2Dirty(false),
    m_isOpt3Dirty(false),
    m_isOpt4Dirty(false),
    m_isOpt5Dirty(false)
{
}

void EffectControls::begin()
{
    isCompressorDirty = &m_isCompressorDirty;
    pinMode(COMPRESSOR_PIN, INPUT);
    attachInterrupt(digitalPinToInterrupt(COMPRESSOR_PIN), compressorInterrupt, RISING);

    isOctaverDirty = &m_isOctaverDirty;
    pinMode(OCTAVER_PIN, INPUT);
    attachInterrupt(digitalPinToInterrupt(OCTAVER_PIN), octaverInterrupt, RISING);

    isDelayDirty = &m_isDelayDirty;
    pinMode(DELAY_PIN, INPUT);
    attachInterrupt(digitalPinToInterrupt(DELAY_PIN), delayInterrupt, RISING);

    isReverbDirty = &m_isReverbDirty;
    pinMode(REVERB_PIN, INPUT);
    attachInterrupt(digitalPinToInterrupt(REVERB_PIN), reverbInterrupt, RISING);

    isOverdriveDirty = &m_isOverdriveDirty;
    pinMode(OVERDRIVE_PIN, INPUT);
    attachInterrupt(digitalPinToInterrupt(OVERDRIVE_PIN), overdriveInterrupt, RISING);

    isMuteDirty = &m_isMuteDirty;
    pinMode(MUTE_PIN, INPUT);
    attachInterrupt(digitalPinToInterrupt(MUTE_PIN), muteInterrupt, RISING);


    delayUs = &m_delayUs;
    isDelayUsDirty = &m_isDelayUsDirty;
    pinMode(DELAY_TAP_PIN, INPUT);
    attachInterrupt(digitalPinToInterrupt(DELAY_TAP_PIN), delayTapInterrupt, RISING);


    isOpt1Dirty = &m_isOpt1Dirty;
    pinMode(OPT_1_PIN, INPUT);
    attachInterrupt(digitalPinToInterrupt(OPT_1_PIN), opt1Interrupt, RISING);

    isOpt2Dirty = &m_isOpt2Dirty;
    pinMode(OPT_2_PIN, INPUT);
    attachInterrupt(digitalPinToInterrupt(OPT_2_PIN), opt2Interrupt, RISING);

    isOpt3Dirty = &m_isOpt3Dirty;
    pinMode(OPT_3_PIN, INPUT);
    attachInterrupt(digitalPinToInterrupt(OPT_3_PIN), opt3Interrupt, RISING);

    isOpt4Dirty = &m_isOpt4Dirty;
    pinMode(OPT_4_PIN, INPUT);
    attachInterrupt(digitalPinToInterrupt(OPT_4_PIN), opt4Interrupt, RISING);

    isOpt5Dirty = &m_isOpt5Dirty;
    pinMode(OPT_5_PIN, INPUT);
    attachInterrupt(digitalPinToInterrupt(OPT_5_PIN), opt5Interrupt, RISING);
}

void EffectControls::update()
{
    if (m_isCompressorDirty)
    {
        m_controllerCommunication.sendToogleEffect(COMPRESSOR_CODE);
        m_isCompressorDirty = false;
    }
    if (m_isOctaverDirty)
    {
        m_controllerCommunication.sendToogleEffect(OCTAVER_CODE);
        m_isOctaverDirty = false;
    }
    if (m_isDelayDirty)
    {
        m_controllerCommunication.sendToogleEffect(DELAY_CODE);
        m_isDelayDirty = false;
    }
    if (m_isReverbDirty)
    {
        m_controllerCommunication.sendToogleEffect(REVERB_CODE);
        m_isReverbDirty = false;
    }
    if (m_isOverdriveDirty)
    {
        m_controllerCommunication.sendToogleEffect(OVERDRIVE_CODE);
        m_isOverdriveDirty = false;
    }
    if (m_isMuteDirty)
    {
        m_controllerCommunication.sendToogleEffect(MUTE_CODE);
        m_isMuteDirty = false;
    }

    if (m_isDelayUsDirty)
    {
        m_controllerCommunication.sendDelayUs(m_delayUs);
        m_isDelayUsDirty = false;
    }

    if (m_isOpt1Dirty)
    {
        applyOpt1();
        m_isOpt1Dirty = false;
    }
    if (m_isOpt2Dirty)
    {
        applyOpt2();
        m_isOpt2Dirty = false;
    }
    if (m_isOpt3Dirty)
    {
        applyOpt3();
        m_isOpt3Dirty = false;
    }
    if (m_isOpt4Dirty)
    {
        applyOpt4();
        m_isOpt4Dirty = false;
    }
    if (m_isOpt5Dirty)
    {
        applyOpt5();
        m_isOpt5Dirty = false;
    }
}

void EffectControls::applyOpt1()
{
    m_controllerCommunication.sendSetEffect(COMPRESSOR_CODE, false);
    m_controllerCommunication.sendSetEffect(OCTAVER_CODE, false);
    m_controllerCommunication.sendSetEffect(DELAY_CODE, false);
    m_controllerCommunication.sendSetEffect(REVERB_CODE, false);
    m_controllerCommunication.sendSetEffect(OVERDRIVE_CODE, false);
}

void EffectControls::applyOpt2()
{
}

void EffectControls::applyOpt3()
{
}

void EffectControls::applyOpt4()
{
}

void EffectControls::applyOpt5()
{
}

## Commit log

2020-03-02 Ajout de la shématique pour la partie analogique.
    [analog.sch, processing.sch]
2020-03-02 Ajout de la schématique pour le MCU
    [MCU.sch, MCU_LED.sch, MCU_control_elements.sch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]
2020-03-02 Modification des MOSFET des LED.
    [MCU.sch, MCU_LED.sch]
2020-03-02 Création d'un projet pour le MCU et finalisation du MCU.
    [MCU.sch, MCU_LED.sch, MCU_control_elements.sch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]
2020-03-02 Ajout du octaver down, ajout du filtre d'anti-aliasing, ajout de l'offset DC et ajout du clipping.
    [analog.sch, octaver_down.sch, processing.sch]
2020-03-02 Enlèvemnt des fichiers de simulation inutile. Ajustement de la fréquence de coupure du filtre d'anti-aliasing.
    [analog.sch]
2020-03-03 Ajout du pcb pour control
    [BOM.ods, MCU.sch, MCU_LED.sch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]
2020-03-03 Correction de pad non connecté
    [control.kicad_pcb]
2020-03-03 Correciton du PCB (espacements entre les connecteurs et polygon pour pour l'ADC.)
    [control.kicad_pcb]
2020-03-03 Ajout des du circuit du psu
    [A+15V_A-15V.sch, A+3.sch, A+9V.sch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]
2020-03-09 Ajout du connecteur pour la footswitch.
    [BOM.ods, MCU.sch, MCU_LED.sch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]
2020-03-09 Ajout du projet et de la schématique de footswitch
    [MCU.sch, MCU_LED.sch, MCU_switchs.sch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]
2020-03-09 Suppresion des fichier *-bak
2020-03-10 Commencement du PCB pour footswitch
    [BOM.ods, MCU_LED.sch, MCU_switchs.sch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]
2020-03-10 Ajout du gnd pour le RX/TX du DSP
    [control.kicad_pcb, control.sch]
2020-03-10 Finalisation du PCB de la footswitch. Correction de la position des mounting holes.
    [control.kicad_pcb, footswitch.kicad_pcb, footswitch.sch]
2020-03-10 Ajout de documentation dans les schématiques
    [MCU.sch, control.kicad_pcb, control.sch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]
2020-03-12 Ajout du PCB du PSU
    [A+15V_A-15V.sch, A+3.sch, A+9V.sch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]
2020-03-12 Ajout du codec et du dsp
    [analog.sch, codec.sch, octaver_down.sch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]
2020-03-16 Ajout des pièces du PCB processing au BOM et assignation des footprints du PCB processing
    [BOM.ods, analog.sch, codec.sch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]
2020-03-17 Ajout d'un lien pour TH
    [BOM.ods]
2020-03-22 Add processing PCB
    [BOM.ods, analog.sch, codec.sch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]
2020-03-26 Ajout des gerber pour control et footswitch.
    [control.GBL, control.GBO, control.GBP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]
2020-03-26 Mise à jour du BOM
    [BOM.ods]
2020-03-28 Déplacement des PCB dans le dossier electronics.
    [A+15V_A-15V.sch, A+3.sch, A+9V.sch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]
2020-03-29 Ajout de time_plot_widget et du widget pour compressor.
2020-03-29 Ajout des widgets manquants pour les effets et ajout des widget dans la fenêtre principale.
2020-03-30 Correction de la mise à jour du graphique lors du changement de signal
2020-03-30 Refactor des widgets des effets. Complétion du code pour octaver.
2020-03-30 Ajout du model pour l'overdrive. Ajout de la lecture de wav
2020-03-30 Correction du nom des axes.
2020-03-31 Ajout du code de l'EQ
2020-04-01 Ajout du code pour calculer les coefficients des filtres pour le contour, la présence et l'EQ.
2020-04-01 Ajout de CompressorDesigner. Correction du nom des tests.
    [main.cpp]
2020-04-02 Ajout du design des filtres butterworth d'ordre 2.
2020-04-02 Changement de l'ordre et des fréquences du filtre pour octaver_up.
2020-04-02 Changement de la fréquence pour presence.
2020-04-02 Ajout de OctaverDesigner. Correction des tests de PresenceDesigner.
    [main.cpp]
2020-04-02 Ajout de DelayDesigner
2020-04-02 Ajout de ReverbDesigner
2020-04-02 Ajout de OverdriveDesigner
2020-04-02 Ajout de l'activation/désactivations des effets.
2020-04-02 Ajout de la classe pour lire les ADC et de la classe pour lire les valeurs de contrôle des effets.
2020-04-02 Ajout de StatusLed
2020-04-02 Ajout de MuteDesigner, commencement du main
2020-04-02 Ajout du contrôleur de la fan.
2020-04-02 Refactor de la structure des dossiers.
2020-04-02 Refactor des effect codes
2020-04-02 Renommage de control à controller.
    [controller.GBL, controller.GBO, controller.GBP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]
2020-04-02 Ajout de la classe pour la communication entre le controlleur et la footswitch.
2020-04-03 Ajout de la communication avec la footswitch dans le main de controller. Ajout des éléments manquants dans la communicaiton.
2020-04-03 Utilisation de Ticker dans le main de controller.
2020-04-03 Enlèmevement des fichiers pour Travis.
2020-04-03 Ajout d'un commande manquante pour la communication de la footswitch
2020-04-03 Ajout d'un ack dans la communication entre la footswitch et le controller.
2020-04-03 Ajout du code pour la footswitch!
2020-04-04 Ajout du heartbeat, ajout du port série de deboguage, correction des tickers.
    [config.h, main.cpp]
2020-04-04 Correction du code pour le Teensy LC.
    [main.cpp]
2020-04-05 Correction du design des filtres.
2020-04-05 Ajout de l'overdrive dans processing.
2020-04-06 Ajout de Mute et de isEnabled dans processing.
2020-04-17 Ajout de la lib manquante
2020-05-07 Changement de la fuse pour le 9v par une efuse
    [A+9V.sch, BOM.ods, psu.kicad_pcb]
2020-06-06 Correction d'erreurs dans PSU
    [BOM.ods, D+12V.sch, psu.kicad_pcb]
2020-07-08 Ajout des fichiers gerber pour le projet psu.
    [psu.kicad_pcb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]
2020-07-10 Création des gerber de processing et correction des gerber de psu.
    [analog.sch, codec.sch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]
2020-07-10 Ajout de la communication avec le DSP dans controller.
2020-07-10 Corrections pour la cohérence des libs.
2020-07-10 Correction des messages des static_assert dans Cs4270.
    [Cs4270.cpp]
2020-07-10 Correction de copier/coller et ajout de la ligne mettant SAI à on.
    [Cs4270.cpp]
2020-07-30 Ajout de la détection du clipping.
2020-07-31 Correction des interrupts TX.
    [Cs4270.cpp, main.cpp]
2020-07-31 Correction du setup des pin du I2S.
    [Cs4270.cpp]
2020-08-23 Correction de la lecture de l'ADC et l'écriture du DAC.
    [Cs4270.cpp]
2020-08-23 Correction D-flip-flop
    [BOM.ods, octaver_down.sch]
2020-08-28 Correction pour l'intrégration.
    [bottom.SLDPRT, button.SLDPRT, case.SLDASM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]
2020-09-01 Ajout du transformateur au BOM
    [BOM.ods]
2020-12-22 Fix footswitch
    [top.SLDPRT]
2022-04-03 Switch the down octave processing to the firmware.
2023-08-11 Add the pitch shifter effect to python tool.
2023-08-12 Fix initialization with the new SDK.
    [ControllerCommunication.cpp, DspCommunication.cpp, config.h]
